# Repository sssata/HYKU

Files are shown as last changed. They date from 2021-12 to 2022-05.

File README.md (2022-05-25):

<p align="center">
  HYKU Logo
  <br>
  
</p>

[Store Link](https://www.tindie.com/products/kappachino/hyku-tablet/)

## First Time Setup Instructions, [Updated for HYKU Configurator v0.6](https://github.com/sssata/HYKU/releases/tag/v0.6.0)

1. Download HYKU_Configurator.exe from [here](https://github.com/sssata/HYKU/releases/tag/v0.6.0).
2. Plug in tablet with a USB-C cable. The LED should light up in a bright rainbow.
3. Deactivate tablet by holding down the keyswitchs for 1 second. The LED should turn blue.
4. Open the HYKU Configurator and open the Tools tab. Ensure tablet is recognized by the program with the "Connected" indicator at the bottom left.
5. Click Fetch Releases button, select latest version (v0.5 as of now), and press Update.
6. After Update completes, the tablet will need to be re-calibrated.
7. To Calibrate, position arm in a straight line as shown in image and press calibrate.
  
2. Reactivate tablet by holding down the keyswitchs for 1 second. The LED should turn bright rainbow.

## Configurator Usage Instructions
1. Configure tablet screen area and tablet area by entering values in the Area Settings tab.
2. Ensure Tablet is plugged in and recognized by the program with the "Connected" indicator at the bottom left.
3. Press the Upload button to apply settings and upload them to the tablet.

## Multi Monitor Instructions
abs mode pic

# What is it?

The HYKU Tablet is a novel drawing tablet-style input device designed from the ground up for osu!.

**Image Below Links to Video:**

IMAGE ALT TEXT HERE (https://www.youtube.com/watch?v=EKBiNb4UB-o)

## Why HYKU?

The goal of the HYKU is to create a pen tablet that is optimized for low latency. Most drawing tablets currently available offer polling rates below 200 Hz and have some level of hardware filtering that further decreases responsiveness, while the HYKU provides 600 Hz of raw sensor output.

<p align="center">
  HYKU Comparison Table
</p>

## Using the HYKU

**The HYKU tablet is plug and play and requires no drivers**. The screen and tablet area settings are written and saved on the tablet through the HYKU Configurator utility.

The configurator utility allows:
- Setting Screen area and Tablet area
- Setting cursor smoothing

<p align="center">
  HYKU Comparison Table
</p>

The tablet features a single button: 

### Download

The latest version of the configurator program can be found in [Releases](https://github.com/sssata/HYKU/releases).

## What's in the Box
- 1x HYKU Tablet, fully assembled
- 1x Tablet Pen, Removable 
- 1x 2m USB Type C to USB Type A Cable

## Tablet Specs

- **Polling Rate:** 600 Hz
- **Max Tablet Area:** Approx. 100mm x 80mm
- **Max Physical Resolution:** Approx. 0.091mm
- **Connector:** USB-C
- **Hot Swappable Switch**
- **OS Compatibility:** Windows 10 64-bit

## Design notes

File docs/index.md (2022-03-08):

<p align="center">
  HYKU Logo
  <br>
  
</p>

# Usage Guide

## First Time Setup Instructions

1. Plug in tablet with a USB-C cable (not included). The LED should light up in a bright rainbow.
2. Deactivate tablet by holding down the keyswitchs for 1 second. The LED should turn blue.
4. Open the HYKU Configurator and open the Tools tab. Ensure tablet is recognized by the program with the "Connected" indicator at the bottom left.
5. Click Fetch Releases button, select latest version, and press Update.
6. After Update completes, the tablet will need to be re-calibrated.
7. To Calibrate, position arm in a straight line as shown in image and press calibrate.
  
2. Reactivate tablet by holding down the keyswitchs for 1 second. The LED should turn bright rainbow.

## Configurator Usage Instructions
1. Configure tablet screen area and tablet area by entering values in the Area Settings tab.
2. Ensure Tablet is plugged in and recognized by the program with the "Connected" indicator at the bottom left.
3. Press the Upload button to apply settings and upload them to the tablet.

# What is it?

The HYKU Tablet is a novel drawing tablet-style input device designed from the ground up for osu!.

<p align="center">
<iframe width="800" height="500" src="https://www.youtube.com/embed/EKBiNb4UB-o" title="YouTube video player" frameborder="0" allow="accelerometer; autoplay; clipboard-write; encrypted-media; gyroscope; picture-in-picture" allowfullscreen></iframe>
</p>

## Why HYKU?

The goal of the HYKU is to create a pen tablet that is optimized for low latency. Most drawing tablets currently available offer polling rates below 200 Hz and have some level of hardware filtering that further decreases responsiveness, while the HYKU provides 600 Hz of raw sensor output.

<p align="center">
  HYKU Comparison Table
</p>

## Using the HYKU

**The HYKU tablet is plug and play and requires no drivers**. The screen and tablet area settings are written and saved on the tablet through the HYKU Configurator utility.

The configurator utility allows:
- Setting Screen area and Tablet area
- Setting cursor smoothing

<p align="center">
  HYKU Comparison Table
</p>

The tablet features a single button: 

### Download

The latest version of the configurator program can be found in [Releases](https://github.com/sssata/HYKU_CAD/releases/tag/v0.1).

## What's in the Box
- 1x HYKU Tablet, fully assembled
- 1x Tablet Pen, Removable 

## Tablet Specs

- **Polling Rate:** 600 Hz
- **Max Tablet Area:** Approx. 100mm x 80mm
- **Max Physical Resolution:** Approx. 0.091mm
- **Connector:** USB-C
- **Hot Swappable Switch**

## Tablet Usage Instructions

1. Plug in tablet with a USB-C cable (not included)
2. Press the key for right mouse button
3. Activate/deactivate tablet by holding down the key for 1 second
4. Configure tablet area and other options by using the HYKU Configurator.

## Configurator Usage Instructions
1. Configure tablet screen area and tablet area by entering values in the Area Settings tab.
2. Ensure Tablet is plugged in and reconized by the program with the "Connected" indicator at the bottom left.
3. Press the Upload button to apply settings and upload them to the tablet.

## Gallery

HYKU Tablett CAD







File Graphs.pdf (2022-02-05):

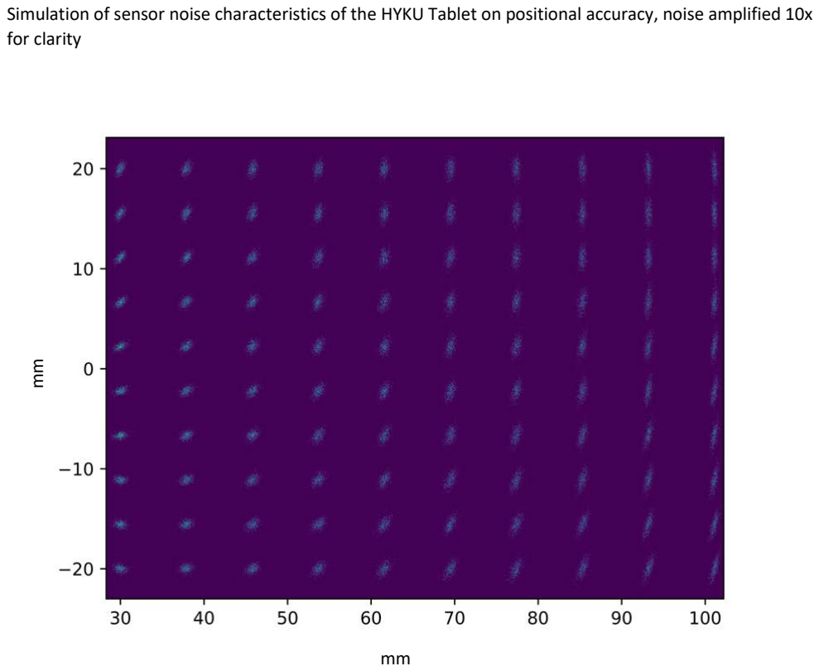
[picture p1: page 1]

Simulation of sensor noise characteristics of the HYKU Tablet on positional accuracy, noise amplified 10x for clarity

mm

mm

Effect of Polling Rate on Position Error during fast movements

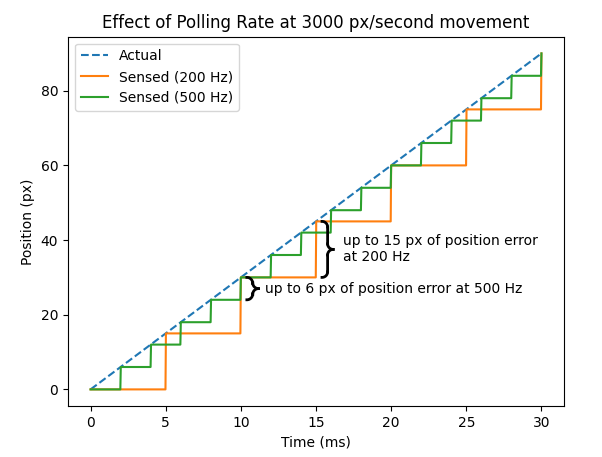
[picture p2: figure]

Note: 3000 px/sec simulates horizontal half cross screen jumps at 160 bpm, 1920x1080 resolution.

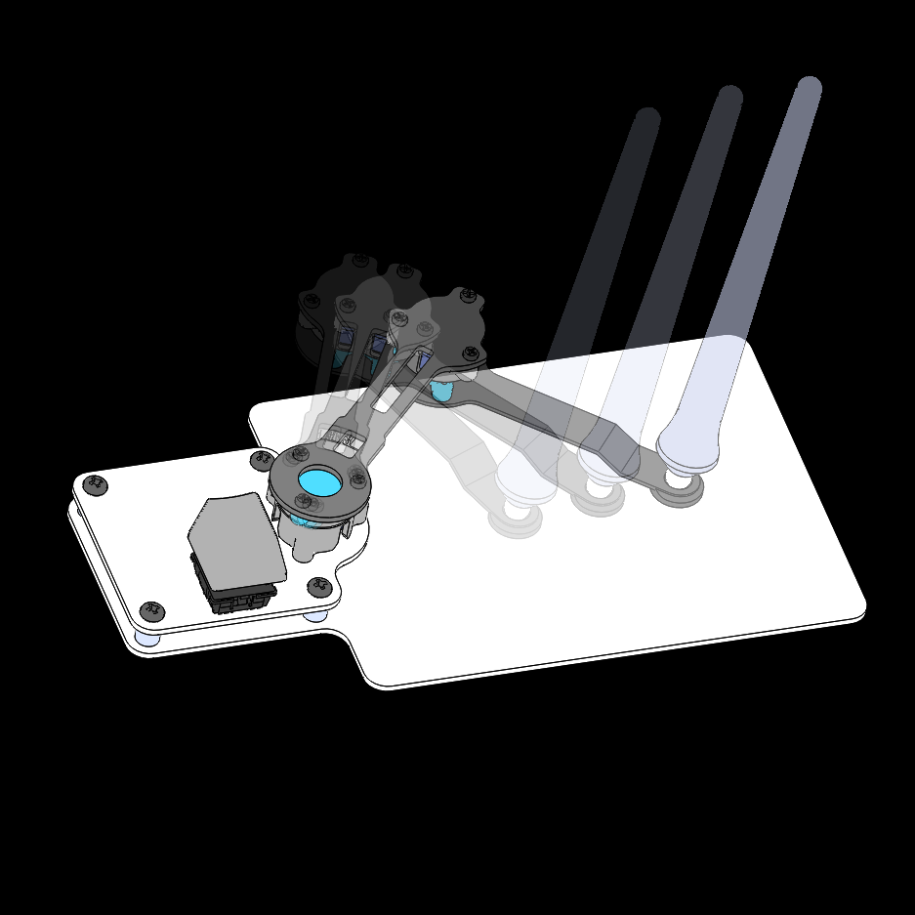
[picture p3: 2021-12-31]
pics/TBL2.png

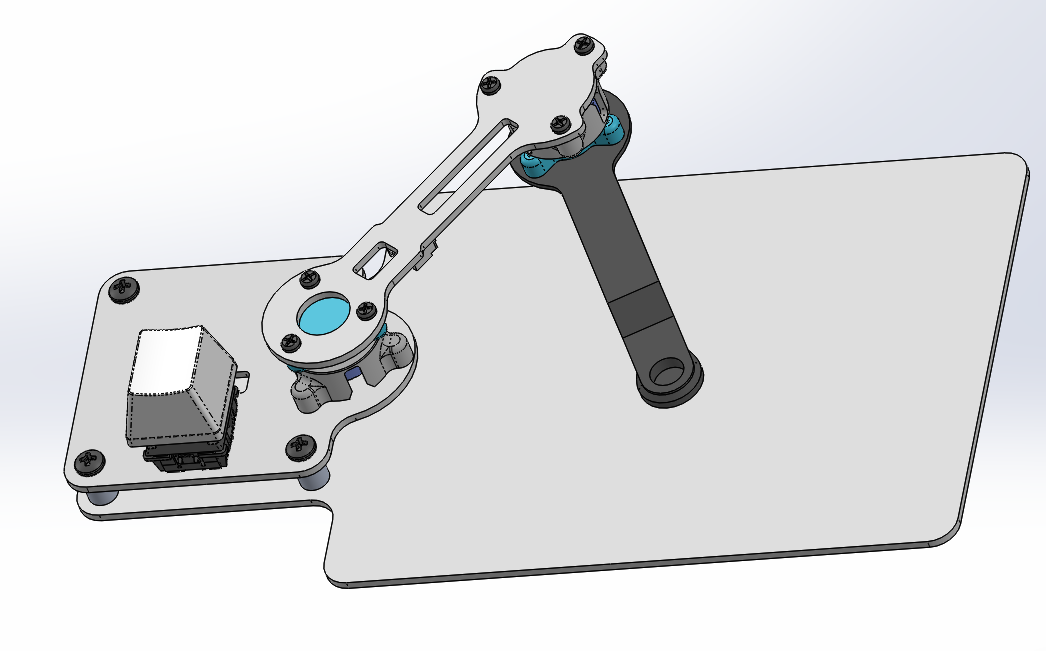
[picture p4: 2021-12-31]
CAD/cad exports/Screenshot 2021-12-27 175426.png

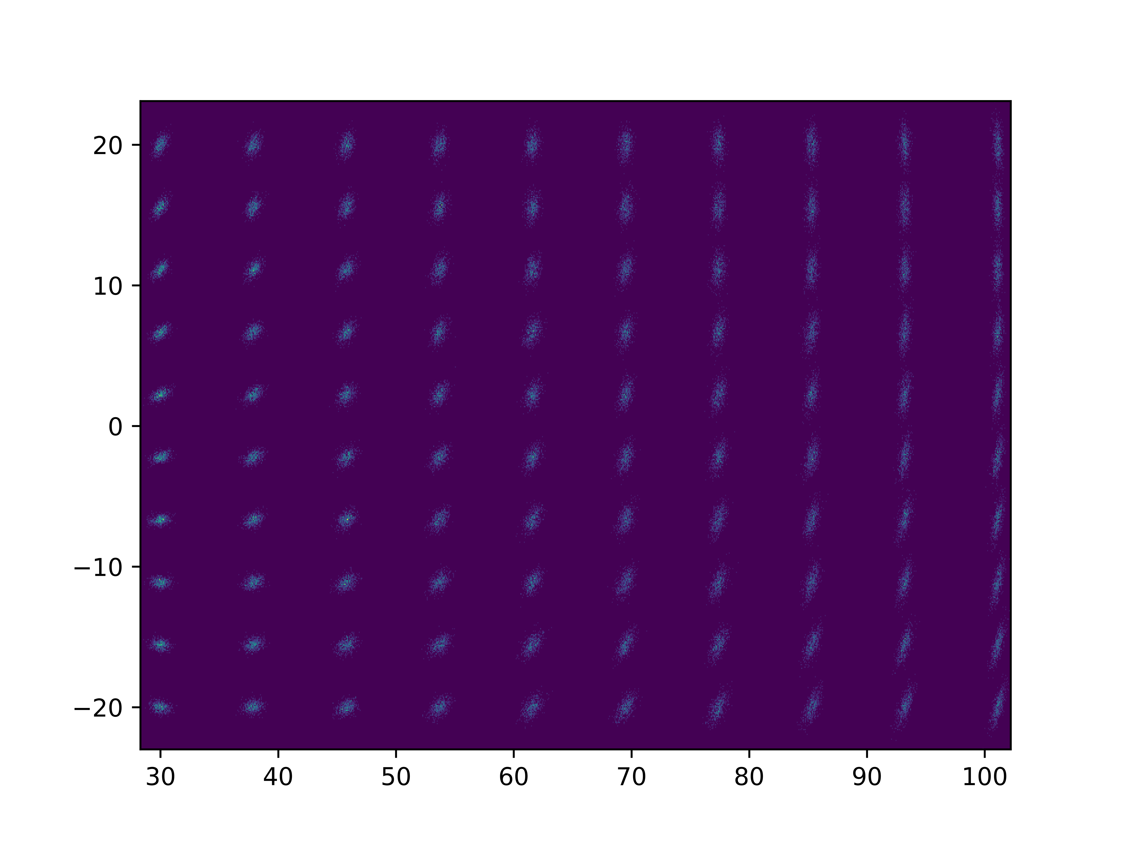
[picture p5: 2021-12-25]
python/output_2021-12-25.png

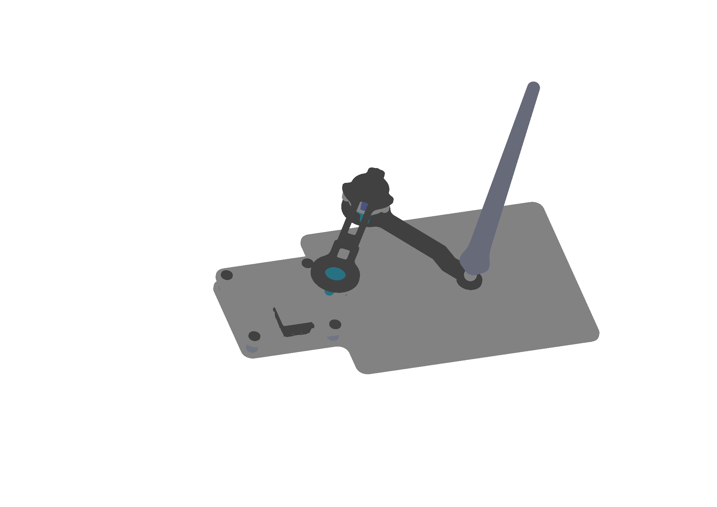
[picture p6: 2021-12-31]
CAD/cad exports/902 FINAL ASSY.JPG

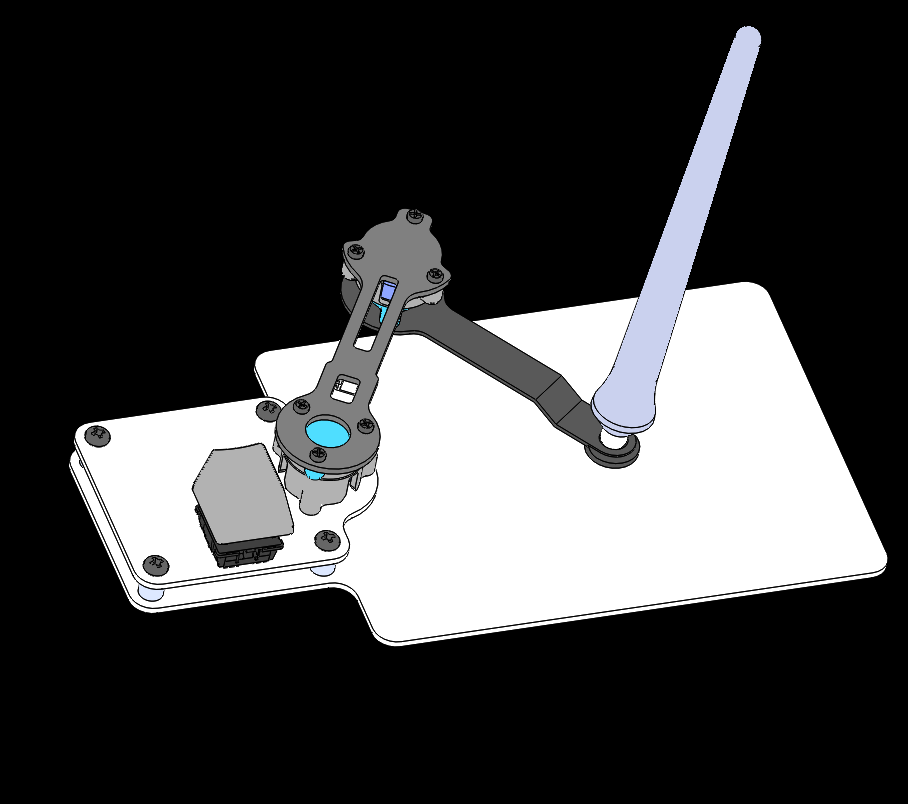
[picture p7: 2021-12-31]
CAD/cad exports/Screenshot 2021-12-27 183334.png

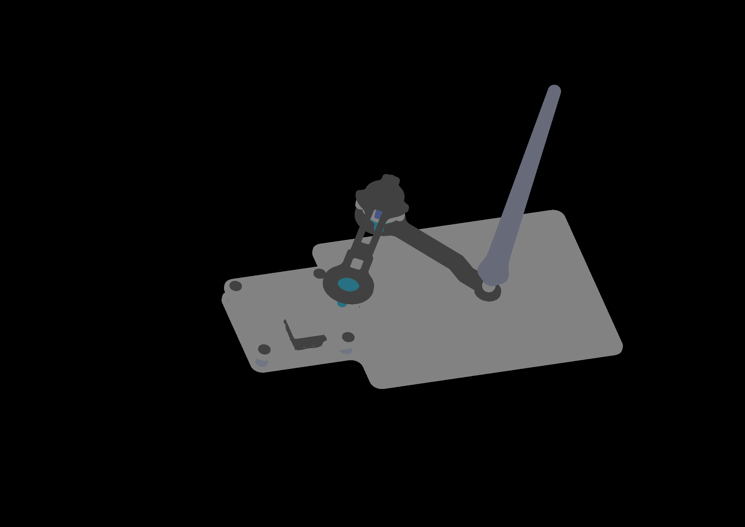
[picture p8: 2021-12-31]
CAD/cad exports/shot.PNG

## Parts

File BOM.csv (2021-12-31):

Source: | C:\Users\Tony\OneDrive - University of Waterloo (1)\TBL2\kicad\base\base.sch
Date: | 2021-12-25 16:54
Tool: | Eeschema (5.1.6)-1
Component Count: | 23
Ref | Value | Footprint | Datasheet | Manufacturer | Vendor
C1 | 100nF | Capacitor_SMD:C_0805_2012Metric | ~
H1 | MountingHole | MountingHole:MountingHole_3.2mm_M3_Pad_Via | ~
H2 | MountingHole | MountingHole:MountingHole_3.2mm_M3_Pad_Via | ~
H3 | MountingHole | MountingHole:MountingHole_3.2mm_M3_Pad_Via | ~
H4 | MountingHole | MountingHole:MountingHole_3.2mm_M3_Pad_Via | ~
J1 | Conn_01x05 | UltraLibrarian:SM05B-NSHSS-TBLFSN | ~
Q1 | MMBT3904 | Package_TO_SOT_SMD:SOT-23 | https://www.fairchildsemi.com/datasheets/2N/2N3904.pdf
Q2 | MMBT3904 | Package_TO_SOT_SMD:SOT-23 | https://www.fairchildsemi.com/datasheets/2N/2N3904.pdf
Q3 | MMBT3904 | Package_TO_SOT_SMD:SOT-23 | https://www.fairchildsemi.com/datasheets/2N/2N3904.pdf
R1 | 5.1k | Resistor_SMD:R_0805_2012Metric | ~
R2 | 10k | Resistor_SMD:R_0805_2012Metric | ~
R3 | 10k | Resistor_SMD:R_0805_2012Metric | ~
R4 | 10k | Resistor_SMD:R_0805_2012Metric | ~
R5 | 65R | Resistor_SMD:R_0805_2012Metric | ~
R6 | 10R | Resistor_SMD:R_0805_2012Metric | ~
R7 | 10R | Resistor_SMD:R_0805_2012Metric | ~
R8 | 5.1k | Resistor_SMD:R_0805_2012Metric | ~
R9 | 5.1k | Resistor_SMD:R_0805_2012Metric | ~
R10 | 5.1k | Resistor_SMD:R_0805_2012Metric | ~
SW2 | SW_SPST_LED_RGB | keyswitches:Kailh_socket_MX_SMD_RGB
U1 | Seeeduiono_Xiao | KeypadLib:Seeeduino_Xiao
U2 | NC7SB3257P6X | Package_TO_SOT_SMD:SOT-363_SC-70-6
U3 | AS5600 | Package_SO:SOIC-8_3.9x4.9mm_P1.27mm

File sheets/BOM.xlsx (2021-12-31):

Unit: One Sellable product
Piece: Non-sellable Individual part
Cost: Amount Paid For parts/shipping
 |  |  |  |  |  | Prod Run A |  |  |  | 48.456 | Prod Run B |  |  |  | 37.0345 | Prod Run C |  |  |  | 32.6252
Subsystem | Name | Description | REF Number (s) | CAD Part Number | MFG Part Number | Qty of Units | Pieces/Unit | Total Pieces | Total Cost | Cost/Unit | Qty of Units | Pieces/Unit | Total Pieces | Total Cost | Cost/Unit | Qty of Units | Pieces/Unit | Total Pieces | Total Cost | Cost/Unit
Base | Base PCB | Base PCB | - | 011 | - | 5 | 1 | 5 | 21 | 4.2 | 20 | 1 | 20 | 22.98 | 1.149 | 50 | 1 | 50 | 44.73 | 0.8946
Base | Capacitor | 0805 100nF | C1, C1 | - | 08055C104KAT2A | 5 | 2 | 10 | 1.01 | 0.202 | 20 | 2 | 40 | 4.04 | 0.202 | 50 | 2 | 100 | 4.46 | 0.0892
Mixed | Connector | JST NSH 5 Pin | J1, J1 | - | SM05B-NSHSS-TBLFSN | 5 | 2 | 10 | 9.11 | 1.822 | 20 | 2 | 40 | 36.44 | 1.822 | 50 | 2 | 100 | 81.8 | 1.636
Base | BJT | LED Switch BJT | Q1, Q2, Q3 | - | BC847BW-7-F | 5 | 3 | 15 | 4.21 | 0.842 | 20 | 3 | 60 | 16.86 | 0.843 | 50 | 3 | 150 | 22.88 | 0.4576
Base | Resistor | 0805 5.1k | R1, R8, R9, R10 | - | RC0805FR-075K1L | 5 | 4 | 20 | 1.24 | 0.248 | 20 | 4 | 80 | 2.48 | 0.124 | 50 | 4 | 200 | 4.96 | 0.0992
Base | Resistor | 0805 10k | R2, R3, R4 | - | RMCF0805FT10K0 | 5 | 3 | 15 | 0.6 | 0.12 | 20 | 3 | 60 | 1.6 | 0.08 | 50 | 3 | 150 | 2.4 | 0.048
Base | Resistor | 0805 68R | R5 | - | RC0805JR-0768RL | 5 | 1 | 5 | 0.75 | 0.15 | 20 | 1 | 20 | 1.06 | 0.053 | 50 | 1 | 50 | 2.13 | 0.0426
Base | Resistor | 0805 10R | R6, R7 | - | RC0805FR-0710RL | 5 | 2 | 10 | 1.22 | 0.244 | 20 | 2 | 40 | 4.88 | 0.244 | 50 | 2 | 100 | 4.98 | 0.0996
Base | Keyswitch | MX Switch | SW2 | - | - | 5 | 1 | 5 | 1.25 | 0.25 | 20 | 1 | 20 | 5 | 0.25 | 50 | 1 | 50 | 12.5 | 0.25
Base | Keycap | Keycap | - | - | - | 5 | 1 | 5 | 1.5 | 0.3 | 20 | 1 | 20 | 6 | 0.3 | 50 | 1 | 50 | 15 | 0.3
Base | Seeeduino Xiao | MCU | U1 | - | 102010328 | 5 | 1 | 5 | 37.25 | 7.45 | 20 | 1 | 20 | 149 | 7.45 | 50 | 1 | 50 | 372.5 | 7.45
Base | I2C Switch | I2C Switch | U2 | - | NC7SB3257P6X | 5 | 1 | 5 | 4.1 | 0.82 | 20 | 1 | 20 | 14.14 | 0.707 | 50 | 1 | 50 | 32.94 | 0.6588
Mixed | Encoder | Rot Hall Encoder 12-Bit | U3, U1 | - | AS5600 | 5 | 2 | 10 | 40.44 | 8.088 | 20 | 2 | 40 | 152.98 | 7.649 | 50 | 2 | 100 | 331.42 | 6.6284
Base | RGB LED | RGB Switch LED | - | - | QBLP677R-RGB | 5 | 1 | 5 | 7.25 | 1.45 | 20 | 1 | 20 | 18.26 | 0.913 | 50 | 1 | 50 | 45.65 | 0.913
Mixed | Wire Assy | 10CM JST NSH 5-Pin Wire | - | - | - | 5 | 1 | 5 | 10 | 2 | 20 | 1 | 20 | 40 | 2 | 50 | 1 | 50 | 100 | 2
Area | Standoff | 4-40 1/4 inch standoff | - | 020 | 4883 | 5 | 4 | 20 | 17 | 3.4 | 20 | 4 | 80 | 61.63 | 3.0815 | 50 | 4 | 200 | 116.32 | 2.3264
Area | Area PCB | Area PCB | - | - | - | 5 | 1 | 5 | 26.95 | 5.39 | 20 | 1 | 20 | 74.62 | 3.731 | 50 | 1 | 50 | 142.8 | 2.856
Mixed | #4-40 Screw | #4-40 1/4 Screw | - | - | - | 5 | 4 | 20 | 3.02 | 0.604 | 20 | 4 | 80 | 3.02 | 0.151 | 50 | 4 | 200 | 6.04 | 0.1208
Upper Arm | Upper Arm PCB | Upper Arm PCB | - | 008 | - | 5 | 1 | 5 | 21 | 4.2 | 20 | 1 | 20 | 22.98 | 1.149 | 50 | 1 | 50 | 44.73 | 0.8946
Mixed | Magnet | 6x2.5mm N35 Radial | - | 009 | 8995 | 5 | 2 | 10 | 4 | 0.8 | 20 | 2 | 40 | 14.27 | 0.7135 | 50 | 2 | 100 | 26.74 | 0.5348
Mixed | M2x5 ST Screw | M2x5 ST Screw | - | - | - | 5 | 12 | 60 | 19.38 | 3.876 | 20 | 12 | 240 | 48.45 | 2.4225 | 50 | 12 | 600 | 116.28 | 2.3256
Mixed | Bearing Mount Male | Bearing Mount Male | - | - | - | 5 | 2 | 10 | 5 | 1 | 20 | 2 | 40 | 20 | 1 | 50 | 2 | 100 | 50 | 1
Mixed | Bearing Mount Female | Bearing Mount Female | - | - | - | 5 | 2 | 10 | 5 | 1 | 20 | 2 | 40 | 20 | 1 | 50 | 2 | 100 | 50 | 1
 |  |  |  |  |  | 5 |  |  |  | 0 | 20 | 0 | 0 |  | 0 | 50 | 0 | 0 |  | 0
 |  |  |  |  |  | 5 |  |  |  | 0 | 20 | 0 | 0 |  | 0 | 50 | 0 | 0 |  | 0
 |  |  |  |  |  | 5 |  |  |  | 0 | 20 | 0 | 0 |  | 0 | 50 | 0 | 0 |  | 0
 |  |  |  |  |  | 5 |  |  |  | 0 | 20 | 0 | 0 |  | 0 | 50 | 0 | 0 |  | 0
 |  |  |  |  |  | 5 |  |  |  | 0 | 20 | 0 | 0 |  | 0 | 50 | 0 | 0 |  | 0
 |  |  |  |  |  | 5 |  |  |  | 0 | 20 | 0 | 0 |  | 0 | 50 | 0 | 0 |  | 0
 |  |  |  |  |  | 5 |  |  |  | 0 | 20 | 0 | 0 |  | 0 | 50 | 0 | 0 |  | 0
 |  |  |  |  |  | 5 |  |  |  | 0 | 20 | 0 | 0 |  | 0 | 50 | 0 | 0 |  | 0
 |  |  |  |  |  |  |  |  |  |  |  | 0 |  |  |  | 50 | 0 | 0 |  | 0
 |  |  |  |  |  |  |  |  |  |  |  | 0 |  |  |  |  | 0
 |  |  |  |  |  |  |  |  |  |  |  | 0 |  |  |  |  | 0
 |  |  |  |  |  |  |  |  |  |  |  | 0 |  |  |  |  | 0
 |  |  |  |  |  |  |  |  |  |  |  | 0 |  |  |  |  | 0
 |  |  |  |  |  |  |  |  |  |  |  | 0 |  |  |  |  | 0
 |  |  |  |  |  |  |  |  |  |  |  | 0 |  |  |  |  | 0
 |  |  |  |  |  |  |  |  |  |  |  | 0 |  |  |  |  | 0
 |  |  |  |  |  |  |  |  |  |  |  | 0 |  |  |  |  | 0
 |  |  |  |  |  |  |  |  |  |  |  | 0 |  |  |  |  | 0
 |  |  |  |  |  |  |  |  |  |  |  | 0 |  |  |  |  | 0
 |  |  |  |  |  |  |  |  |  |  |  | 0 |  |  |  |  | 0
 |  |  |  |  |  |  |  |  |  |  |  | 0 |  |  |  |  | 0
 |  |  |  |  |  |  |  |  |  |  |  | 0 |  |  |  |  | 0
 |  |  |  |  |  |  |  |  |  |  |  | 0 |  |  |  |  | 0
 |  |  |  |  |  |  |  |  |  |  |  | 0 |  |  |  |  | 0
 |  |  |  |  |  |  |  |  |  |  |  | 0 |  |  |  |  | 0
 |  |  |  |  |  |  |  |  |  |  |  | 0 |  |  |  |  | 0
 |  |  |  |  |  |  |  |  |  |  |  | 0 |  |  |  |  | 0
 |  |  |  |  |  |  |  |  |  |  |  | 0 |  |  |  |  | 0
 |  |  |  |  |  |  |  |  |  |  |  | 0 |  |  |  |  | 0
 |  |  |  |  |  |  |  |  |  |  |  | 0 |  |  |  |  | 0
 |  |  |  |  |  |  |  |  |  |  |  | 0 |  |  |  |  | 0
 |  |  |  |  |  |  |  |  |  |  |  | 0 |  |  |  |  | 0
 |  |  |  |  |  |  |  |  |  |  |  | 0 |  |  |  |  | 0
 |  |  |  |  |  |  |  |  |  |  |  | 0 |  |  |  |  | 0
 |  |  |  |  |  |  |  |  |  |  |  | 0 |  |  |  |  | 0
 |  |  |  |  |  |  |  |  |  |  |  | 0 |  |  |  |  | 0
 |  |  |  |  |  |  |  |  |  |  |  | 0 |  |  |  |  | 0
 |  |  |  |  |  |  |  |  |  |  |  | 0 |  |  |  |  | 0
 |  |  |  |  |  |  |  |  |  |  |  | 0 |  |  |  |  | 0
 |  |  |  |  |  |  |  |  |  |  |  | 0 |  |  |  |  | 0
 |  |  |  |  |  |  |  |  |  |  |  | 0 |  |  |  |  | 0
 |  |  |  |  |  |  |  |  |  |  |  | 0 |  |  |  |  | 0
 |  |  |  |  |  |  |  |  |  |  |  | 0 |  |  |  |  | 0
 |  |  |  |  |  |  |  |  |  |  |  | 0 |  |  |  |  | 0
 |  |  |  |  |  |  |  |  |  |  |  | 0 |  |  |  |  | 0
 |  |  |  |  |  |  |  |  |  |  |  | 0 |  |  |  |  | 0
 |  |  |  |  |  |  |  |  |  |  |  | 0 |  |  |  |  | 0
 |  |  |  |  |  |  |  |  |  |  |  | 0 |  |  |  |  | 0
 |  |  |  |  |  |  |  |  |  |  |  | 0 |  |  |  |  | 0
 |  |  |  |  |  |  |  |  |  |  |  | 0 |  |  |  |  | 0
 |  |  |  |  |  |  |  |  |  |  |  | 0 |  |  |  |  | 0
 |  |  |  |  |  |  |  |  |  |  |  | 0 |  |  |  |  | 0
 |  |  |  |  |  |  |  |  |  |  |  | 0 |  |  |  |  | 0
 |  |  |  |  |  |  |  |  |  |  |  | 0 |  |  |  |  | 0
 |  |  |  |  |  |  |  |  |  |  |  | 0 |  |  |  |  | 0
 |  |  |  |  |  |  |  |  |  |  |  | 0 |  |  |  |  | 0
 |  |  |  |  |  |  |  |  |  |  |  | 0 |  |  |  |  | 0
 |  |  |  |  |  |  |  |  |  |  |  | 0 |  |  |  |  | 0
 |  |  |  |  |  |  |  |  |  |  |  | 0 |  |  |  |  | 0
 |  |  |  |  |  |  |  |  |  |  |  | 0 |  |  |  |  | 0
 |  |  |  |  |  |  |  |  |  |  |  | 0 |  |  |  |  | 0
 |  |  |  |  |  |  |  |  |  |  |  | 0 |  |  |  |  | 0

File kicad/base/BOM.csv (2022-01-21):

Comment | Designator | Footprint | LCSC
100nF | C1 | Capacitor_SMD:C_0805_2012Metric | C49678
MMBT3904 | Q1,Q2,Q3 | Package_TO_SOT_SMD:SOT-23 | C20526
5.1k | R1,R8,R9,R10 | Resistor_SMD:R_0805_2012Metric | C27834
10k | R2,R3,R4 | Resistor_SMD:R_0805_2012Metric | C17414
68R | R5 | Resistor_SMD:R_0805_2012Metric | C17802
10R | R6,R7 | Resistor_SMD:R_0805_2012Metric | C17415

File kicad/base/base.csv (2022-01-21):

Id | Designator | Package | Quantity | Designation | Supplier and ref
1 | REF**,REF**,REF** | JLCPCB Tooling Hole | 3 | JLCPCB Tooling Hole
2 | U3 | SOIC-8_3.9x4.9mm_P1.27mm | 1 | AS5600
3 | U1 | Seeeduino_Xiao | 1 | Seeeduiono_Xiao
4 | SW2 | Kailh_socket_MX_SMD_RGB | 1 | SW_SPST_LED_RGB
5 | R10,R9,R8,R1 | R_0805_2012Metric | 4 | 5.1k
6 | Q3,Q2,Q1 | SOT-23 | 3 | MMBT3904
7 | R7,R6 | R_0805_2012Metric | 2 | 10R
8 | R5 | R_0805_2012Metric | 1 | 68R
9 | J1 | SM05B-NSHSS-TBLFSN | 1 | TO ARM
10 | H4,H3,H2,H1 | MountingHole_3.2mm_M3_Pad_Via | 4 | MountingHole
11 | C1 | C_0805_2012Metric | 1 | 100nF
12 | R2,R3,R4 | R_0805_2012Metric | 3 | 10k
13 | U2 | SOT-363_SC-70-6 | 1 | NC7SB3257P6X

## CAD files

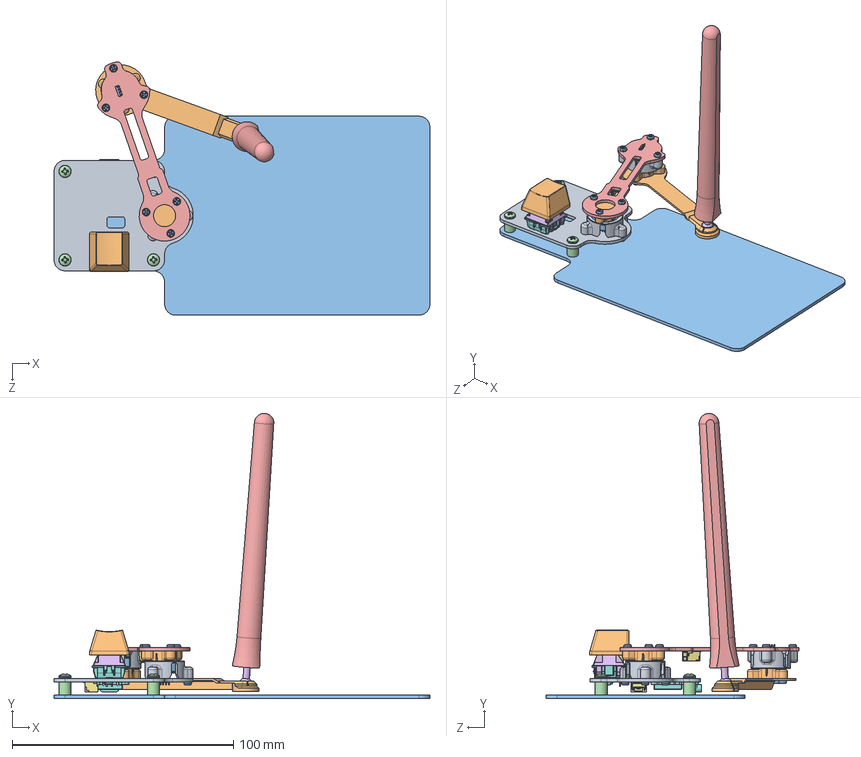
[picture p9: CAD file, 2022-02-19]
CAD/902 FINAL ASSY.SLDASM
170.0 x 129.0 x 114.6 mm
005 BEARING FEMALE PLATE x 2
006 BEARING MALE PLATE x 2
007 6700ZZ bearing x 2
009 6x2mm MAGNET x 2
008 UPPER ARM PCB
013 AS5600 SOIC-8 x 2
014 JST NSH 5 PIN BOARD SIDE x 2
012 SeeeduinoXiao3D
011 BASE PCB
016 LOWER ARM PCB
017 AREA PCB
020 STANDOFF 3x6 x 4
Cherry MX Stem
Cherry MX Top Housing
Cherry MX Bottom Housing
Cherry MX Pins
Cherry MX OEM R4 Keycap
99461A914_Phillips Rounded Head Thread-Forming Screws x 12
91772A106_Passivated 18-8 Stainless Steel Pan Head Phillips Screw x 4
021 PEN
022 PEN NIB

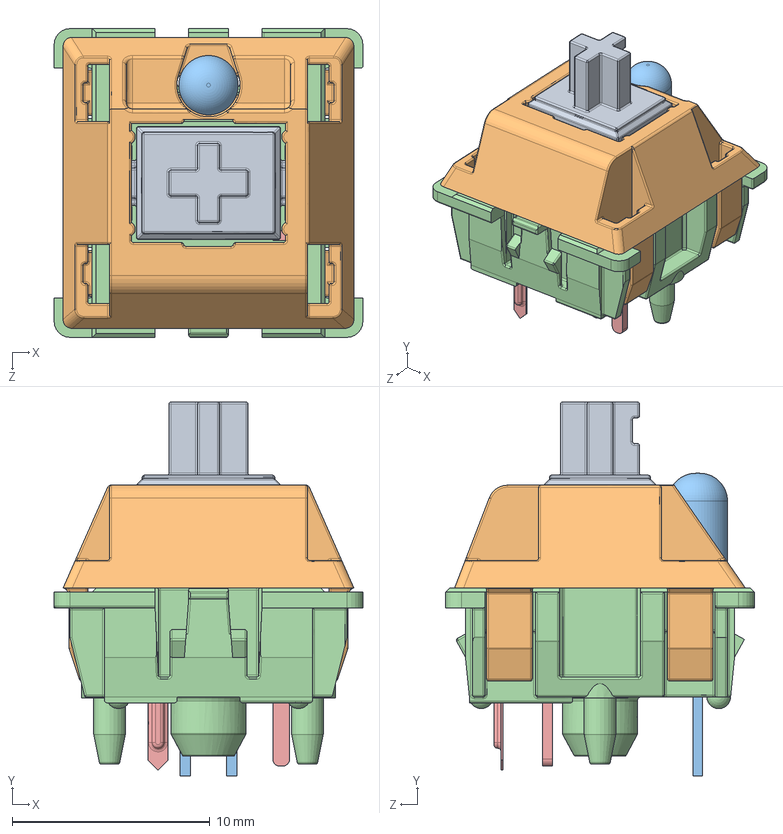
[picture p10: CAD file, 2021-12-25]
CAD/imported/CHERRY MX Switch.SLDASM
15.6 x 18.9 x 15.6 mm
Cherry MX Stem
Cherry MX Top Housing
Cherry MX Bottom Housing
Cherry MX Pins

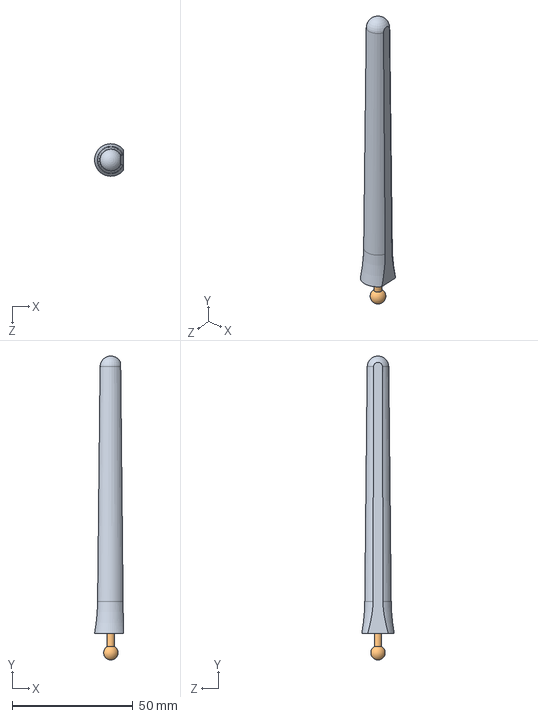
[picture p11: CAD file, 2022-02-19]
CAD/906 PEN ASSY.SLDASM
12.0 x 126.0 x 13.5 mm
021 PEN
022 PEN NIB

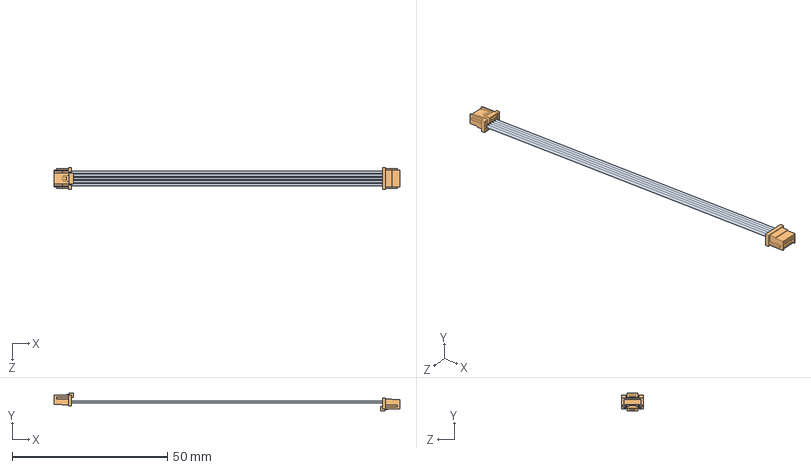
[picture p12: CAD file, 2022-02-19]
CAD/905 WIRE ASSY.SLDASM
111.4 x 5.75 x 7.00 mm
018 UPPER WIRE
015 JST NSH 5 PIN WIRE SIDE x 2
020 JST NSH CRIMP x 10

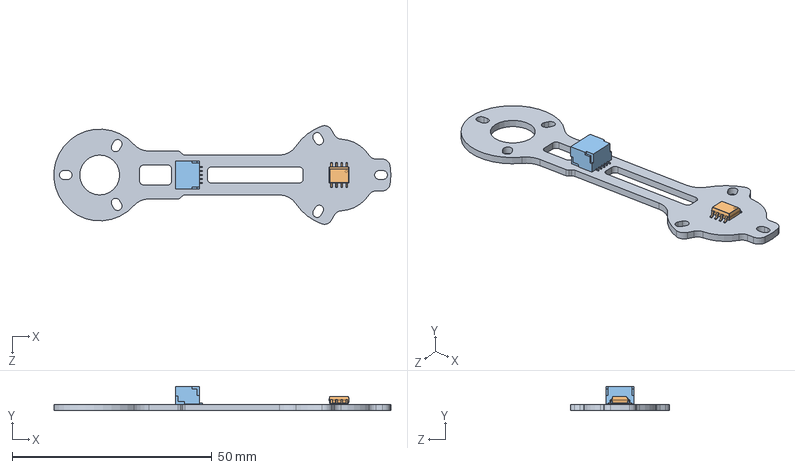
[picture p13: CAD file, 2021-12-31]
CAD/904 UPPER ARM PCB ASSY.SLDASM
84.4 x 6.10 x 24.7 mm
008 UPPER ARM PCB
013 AS5600 SOIC-8
014 JST NSH 5 PIN BOARD SIDE

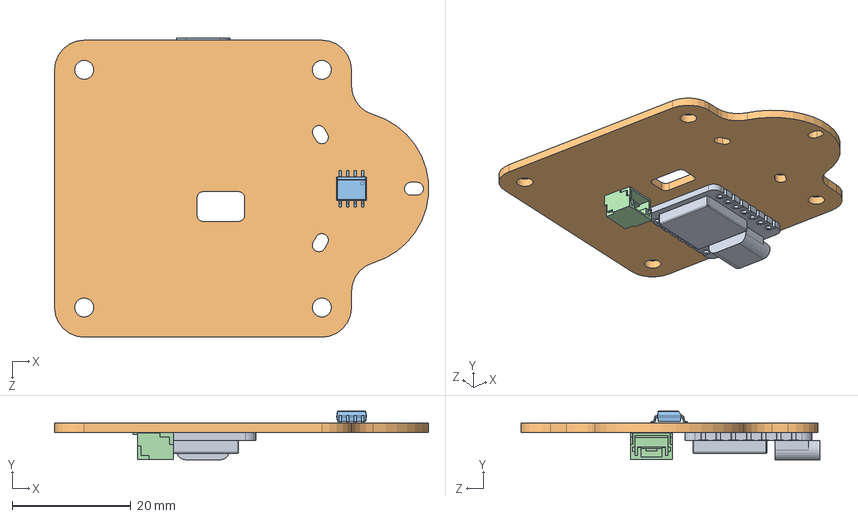
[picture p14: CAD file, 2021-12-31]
CAD/903 BASE PCB ASSY.SLDASM
63.0 x 8.20 x 50.4 mm
012 SeeeduinoXiao3D
011 BASE PCB
013 AS5600 SOIC-8
014 JST NSH 5 PIN BOARD SIDE

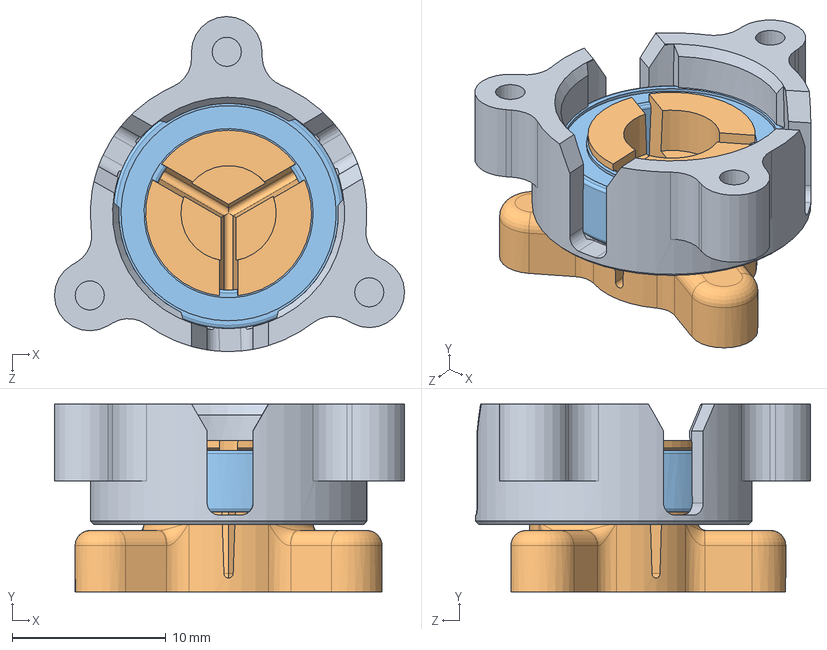
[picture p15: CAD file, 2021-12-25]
CAD/901 BEARING ASSY.SLDASM
22.8 x 12.2 x 21.8 mm
005 BEARING FEMALE PLATE
006 BEARING MALE PLATE
007 6700ZZ bearing

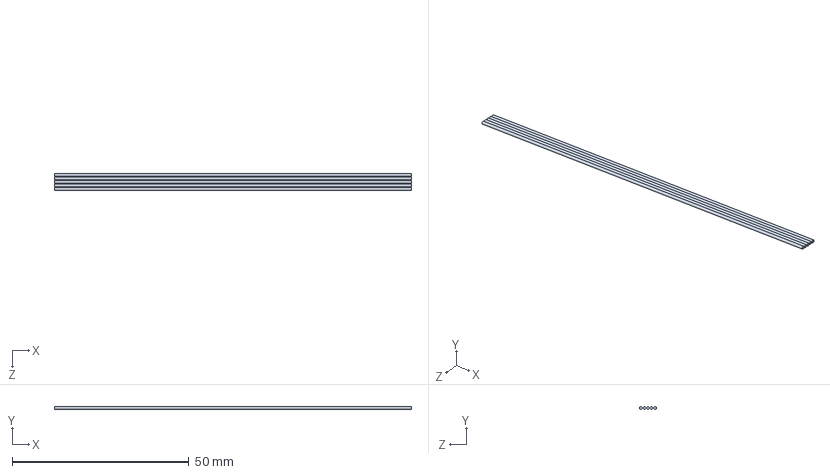
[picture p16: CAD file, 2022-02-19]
CAD/018 UPPER WIRE.SLDPRT
101.0 x 0.8 x 4.80 mm

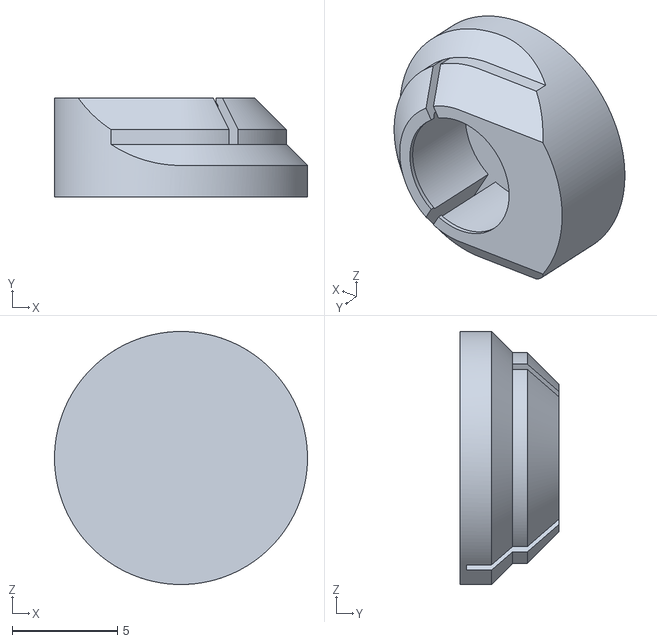
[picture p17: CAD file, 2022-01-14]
CAD/cad exports/016 LOWER ARM TEST1.STL
12.0 x 4.70 x 12.0

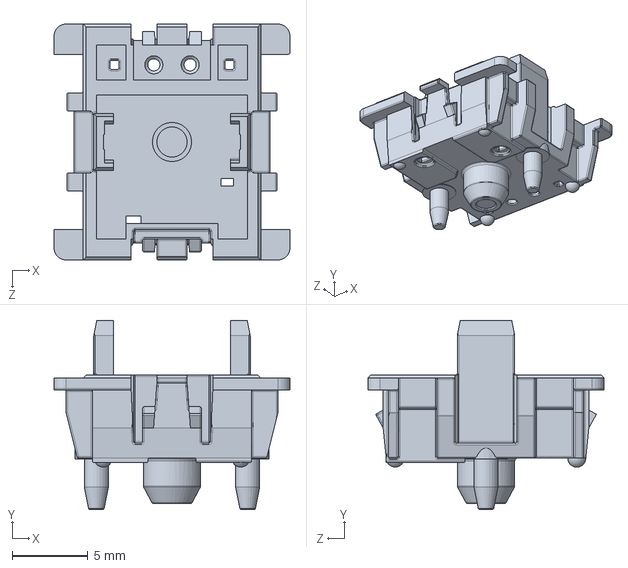
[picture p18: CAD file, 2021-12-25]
CAD/imported/Cherry MX Bottom Housing.SLDPRT
15.6 x 12.5 x 15.6 mm

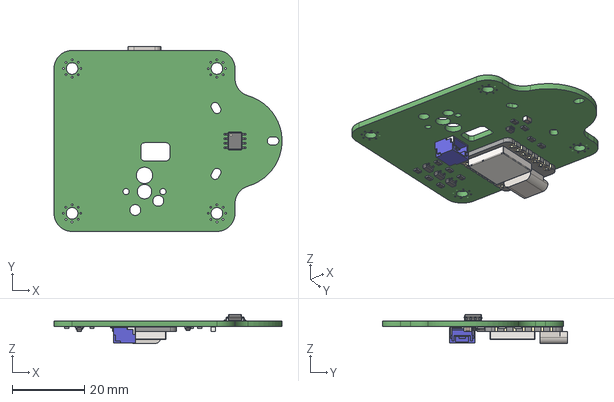
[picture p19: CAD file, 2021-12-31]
kicad/base/kicad export/base.step
63.0 x 51.1 x 8.05 mm

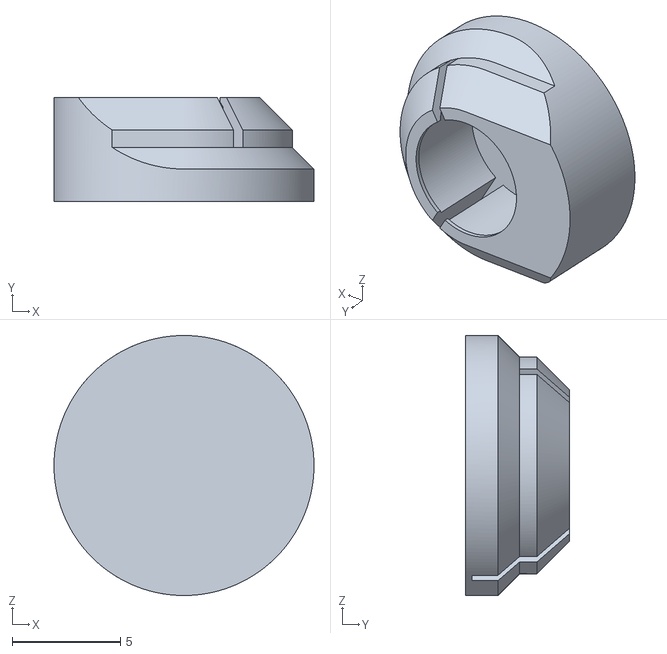
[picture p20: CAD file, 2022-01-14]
CAD/cad exports/016 LOWER ARM TEST3.STL
12.0 x 4.80 x 12.0

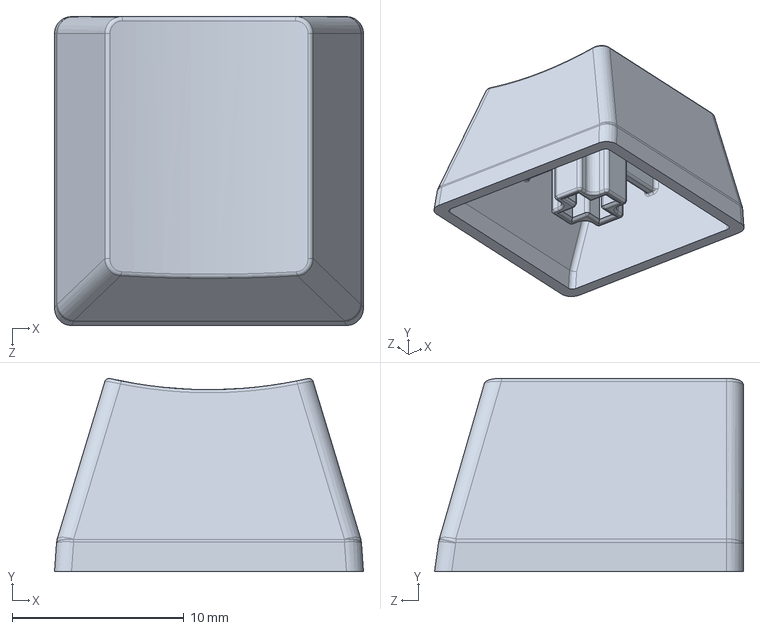
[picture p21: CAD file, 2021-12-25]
CAD/imported/Cherry MX OEM R4 Keycap.SLDPRT
18.0 x 11.3 x 18.0 mm

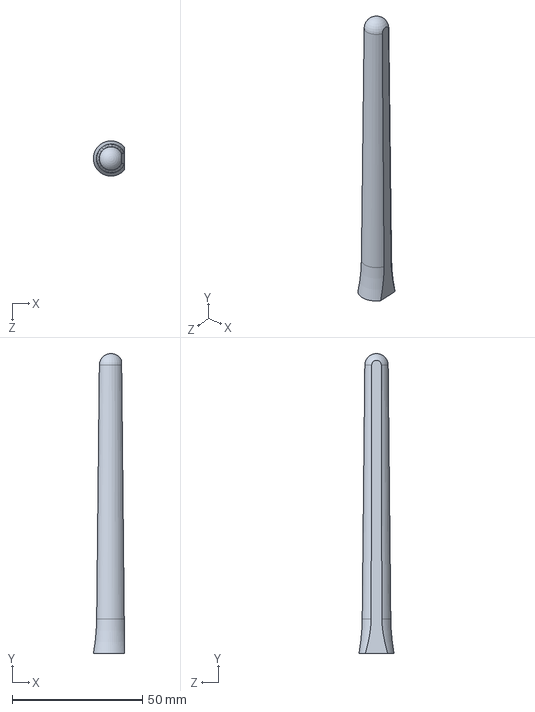
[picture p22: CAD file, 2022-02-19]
CAD/021 PEN.SLDPRT
12.0 x 115.0 x 13.5 mm

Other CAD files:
CAD/cad exports/016 LOWER ARM TEST2.STL
CAD/cad exports/008 UPPER ARM PCB2.DXF
CAD/imported/Cherry MX Pins.SLDPRT
CAD/006 BEARING MALE PLATE.SLDPRT
CAD/001 BASE REV2.SLDPRT
CAD/002 UPPER ARM REV2.SLDPRT
CAD/003 LOWER ARM REV2.SLDPRT
CAD/004 MR85ZZ bearing.SLDPRT
CAD/005 BEARING FEMALE PLATE.SLDPRT
CAD/007 6700ZZ bearing.SLDPRT
CAD/008 UPPER ARM PCB.SLDPRT
CAD/009 6x2mm MAGNET.SLDPRT
CAD/010 BASE KICAD EXP.SLDPRT
CAD/010 BASE.SLDPRT
CAD/011 BASE PCB.SLDPRT
CAD/012 SeeeduinoXiao3D.SLDPRT
CAD/013 AS5600 SOIC-8.SLDPRT
CAD/014 JST NSH 5 PIN BOARD SIDE.SLDPRT
CAD/014.SLDDRW
CAD/015 JST NSH 5 PIN WIRE SIDE.SLDPRT
CAD/016 LOWER ARM PCB.SLDPRT
CAD/017 AREA PCB.SLDPRT
CAD/019.SLDPRT
CAD/020 JST NSH CRIMP.SLDPRT
CAD/020 STANDOFF 3x6.SLDPRT
CAD/022 PEN NIB.SLDPRT
CAD/905 WIRE ASSY.SLDDRW
CAD/905.SLDDRW
CAD/cad exports/004 MR85ZZ bearing.STL
CAD/cad exports/005 BEARING FEMALE PLATE.STL
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

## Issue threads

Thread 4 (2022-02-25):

Multi monitor support

jasonhahm, 2022-02-25:
It doesn't seem like it's working with multi monitor environment.
I currently have three monitors, and the configurator still shows 1920*1080, and the screen area is basically stretched on the tablet.
Can we have an option to choose one of the active monitors?

sssata, 2022-02-25:
Hi thanks for bringing this up, multi-monitor support is currently a work in progress.

sssata, 2022-03-06:
Update: still on it, for now try activating the "Map absolute raw input to the osu! window" setting in osu.
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

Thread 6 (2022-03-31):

config.exe unable to detect device

Jaymusta, 2022-03-31:
Hi there,

I've recently attempted to update the firmware for my tablet to v0.5, but it would seem that HYKU_Configurator.exe stopped responding shortly after the CMD window popped up.

I went ahead and restarted the executable, but it would seem that the program isn't able to detect the tablet anymore.

I suspect that the tablet may be stuck in a certain mode given that its LED is fading between green and yellow/orange as it may have been waiting for the executable to flash the firmware to the device around when it stopped responding.

### Some details that may have contributed to this happening include:

- I replaced the version of the executable to the latest build (v0.5) from a previous version that didn't have a third tab dedicated to calibrating and flashing new firmware to the device before doing any of this
- Upon seeing how that new executable required me to update the firmware on the device to v0.5 in order to upload any settings, I went ahead and fetched the firmware in that 3rd tab and attempted to start that process with v0.5 of the .exe instead of v0.4 of the .exe

### What I have tried to remedy this issue so far:

- reconnecting the tablet with the executable open/running
- reconnecting the tablet and holding down the gateron switch while plugging the cable back into it with the executable open/running
- ^doing both of those things with the executable closed, and then opening/running the executable
- ^doing all of the above with the previous version of the executable that I was using prior to this

### Here are the error prompts I currently get when trying to upload any settings or flash any firmware to the device:
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

An additional detail I just now found is that Device Manager does seem to respond to me disconnecting/reconnecting the device to the computer along with the usb device connection sounds playing.

If my tablet is indeed stuck in a certain mode waiting for the .exe to flash firmware to it, is there a way to reset the device? (so that it would able to reconnect to my pc in its "factory" default mode which would be detectable to the .exe)

sssata, 2022-03-31:
Hi Jaymusta, sorry you're having trouble and really appreciate the detailed issue report.

Can you try entering bootloader mode as described [here](https://wiki.seeedstudio.com/Seeeduino-XIAO/#enter-bootloader-mode)? You may need to unscrew the main board from the base to access the pads, and you may want to use tape to cover the USB-C connector and any surrounding pads so you don't accidentally short them.

The pads to short should be somewhere around here:
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

After entering the bootloader mode, both the green and yellow LEDs beside the USB connector should be lit and the device should be recognized by Windows as a USB Serial Device. At this point, you can try re-uploading the v0.5 firmware through the configurator program.

Jaymusta, 2022-04-01:
Hey thanks for replying,

Upon taking a better look at those LEDs, it seems that the green LED was actually staying on with the yellow LED slowly fading on and off.

I went ahead and followed those instructions after finding those 2 contact pads next to the USB-C port as you specified, and the yellow LED did respond to me shorting those 2 contact pads with tweezers in that it stayed off while the tweezers were maintaining contact with the pads.

Unfortunately, it seems that the yellow LED just went back to its previous behavior of slowly fading on and off after flickering once right after shorting those pads twice as instructed via that link you provided.

It also seems that the way my PC is reading the device hasn't changed either since HYKU_Configurator.exe didn't recognize the device after shorting those pads.

I did find the device within Device Manager:
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

Along with the last event my pc logged with the device in Event Viewer from about 2 hours ago:

> Source: UserPnp
> Event ID: 20001
> Task Category: (7005)

> Driver Management concluded the process to install driver wpdfs.inf_amd64_aade15d7efbed3c9 for Device Instance ID SWD\WPDBUSENUM\_??_USBSTOR#DISK&VEN_SEEEDUIN&PROD_O_XIAO&REV_1.00#8&1241C78E&0&B8335C6650555233362E3120FF081738&0#{53F56307-B6BF-11D0-94F2-00A0C91EFB8B} with the following status: 0x0.

^All that information might be doing is just confirming that my PC is still not recognizing the device properly, but I went ahead and included it anyways just in case.

Jaymusta, 2022-04-02:
I ended up going further down the rabbit hole regarding what came up in the google search results when searching for similar experiences with the Seeduino XIAO board.

I ended up finding [this forum post](https://forum.seeedstudio.com/t/possible-reset-boot-loader-problem/252560) where the OP ended up experiencing what seems similar to the situation I'm currently experiencing here.

However, upon seeing how the recommendation was to purchase and use an external device to flash a functional bootloader into the board, I ended up searching for an alternate method.

As a result, I came across [this medium article](https://naidoff.medium.com/how-to-unbrick-seeduino-xiao-board-without-external-programmer-if-it-was-bricked-while-flashing-fbed494a5034) that provided instructions on how to do that without an external device.

In hindsight, I probably should have run this by you before going any further (especially since my programming knowledge is limited to the basics of C++), but it seems like the bootloader in my device is more functional in that the device isn't stuck/hung up wherever it was before I followed that guide.

Despite all this, there has been no change with HYKU_Configurator.exe's ability to detect the device (including how that same serial exception port error popping up when attempting to flash firmware).

Though now that the bootloader seems like it may actually be in a functional state, there may be a way to flash the firmware or maybe even upload a sketch as mentioned in that medium article.

sssata, 2022-04-02:
Thanks for all the extra work you put in. When you plug in the tablet, does a device called "USB Serial Device" show up in device manager?
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

If so, can you right click on it, open up properties, select the details tab, select "Device instance path" in the dropdown, and get the resulting value listed?

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

In addition, does your computer ever see the tablet as a removable disk drive when you plug it in?

Jaymusta, 2022-04-02:
Ah yes this entire time, it seems that the tablet has consistently shown up as "USB Serial Device (COM3)" in device manager (both before and after flashing the bootloader).

Here is its Device instance path:
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

> USB\VID_2886&PID_002F&MI_00\7&35524896&1&0000

Though after flashing the bootloader, it seems that it also defaults to showing up as "USB Serial Device (COM5)" whenever I have it go into bootloader mode.

So I'm gonna go ahead and include the Device instance path for that as well:
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

> USB\VID_2341&PID_8036&MI_00\9&AA39334&0&0000

sssata, 2022-04-05:
Ok, can you try downloading the .uf2 file from [here](https://github.com/sssata/HYKU_Firmware/releases/tag/v0.5) and drag and drop the file onto the removable disk that appears when you plug the tablet in?

Something like this [tutorial](https://learn.adafruit.com/adafruit-feather-m0-express-designed-for-circuit-python-circuitpython/uf2-bootloader-details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).
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
sssata, 2022-04-09:
1. Yes, the configurator settings are stored on the tablet specifically so you don't have to run some annoying program in the background.

2. The osu map raw input workaround shouldn't have any latency side effects as far as I'm aware.

That being said, thanks so much for all your support on this project, it really helps keep me motivated to work on this. It would be super cool if you do made a video, I'm all for it.

I'd be glad to listen to your feedback here on this git issue.

Jaymusta, 2022-04-11:
- Ayy love to see it.

> That being said, thanks so much for all your support on this project, it really helps keep me motivated to work on this. It would be super cool if you do made a video, I'm all for it.

Man it's crazy how contagious good vibes from things like this can be. This might have just helped me start bringing the momentum back on my end of things.

> I'd be glad to listen to your feedback here on this git issue.

Ah alright, here we go:

### Feedback

- The 3D printed "tablet pen" isn't completely round, which has continued to be a source of frustration while playing osu! so far. The flat side, which I assume is the side that was in contact with the 3D printing surface, often distracts me as I seem to constantly shift my grip around subconsciously. This results in me focusing more on my pen grip more than just playing the game (wrapping grip tape seems to have lessened this a little, though it's definitely still making it harder for any muscle memory to adjust to consistently).
- After my first 2 game sessions with the tablet, I went ahead and applied some tennis grip tape on the lower half of the pen. I ended up having to get some super glue since the tension of wrapping that half of the pen caused it to snap, and [I needed to glue it back together](https://imgur.com/a/SsiUR9R).
- I had no other real issues with the hardware so far, but I did manage to improve how it felt to drag the pen around by creating an incline of sorts with some washers I glued to the rubber feet in the back two corners.
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
I ended up adding 3 washers to each side, adding a total of 3mm of height to the back of the tablet's surface. This made the the tablet match the angle of incline that my old CTH-480 has, and ended up really making a significant improvement in the general feeling of playing osu! with it.

- Finally, other than concerns with having to deal with a device in its developmental stages, one of my friends mentioned how the main thing stopping him from trying the tablet out is that [its max active area's width is considerably smaller than his own tablet area](https://imgur.com/a/aC84bFZ). I believe his current tablet area is still around 120mm in width.

### Suggestions

- I'm not completely familiar with the processes involved with 3D printing objects/parts, but I think altering the process in which the "tablet pen" is printed could help to address the flat edge and durability issues above. There does seem to be another flat surface where the ball joint is screwed in to, so maybe having that surface be in contact with the 3D printing plate could be something to look into. As for the durability, maybe using a more durable type of plastic that doesn't sacrifice too much weight could help if altering the printing patterns doesn't end up helping much with that in mind.
- On the topic of the tablet pen, maybe adding different options for different pen shapes on the product page could be something to add if viable given how its currently 3D printed. Something like having those options be based on the shapes of tablet pens from other known brands: Wacom, Huion, XP-Pen, GAOMON, VEIKK, and maybe even an original pen shape that combines different things from those other brands' pen shapes.
- As for the incline of the tablet's surface, maybe adding the option to choose between rubber pads of different thicknesses to stick onto those back two corners of the device could be something to consider. It's possible that offering differently sized rubber pads would be more viable compared to adding a mechanism similar to what keyboards may have for this purpose.
- And I'm sure the topic/idea of increasing the maximum active area of the tablet has already been introduced by others in the community. So I'm sure you have some kind of solution for that planned out to be addressed eventually (probably once the software side of things are more concrete).

I believe that's pretty much all I have for now, though I'll be sure to add anything else that comes to mind as I keep using the tablet.

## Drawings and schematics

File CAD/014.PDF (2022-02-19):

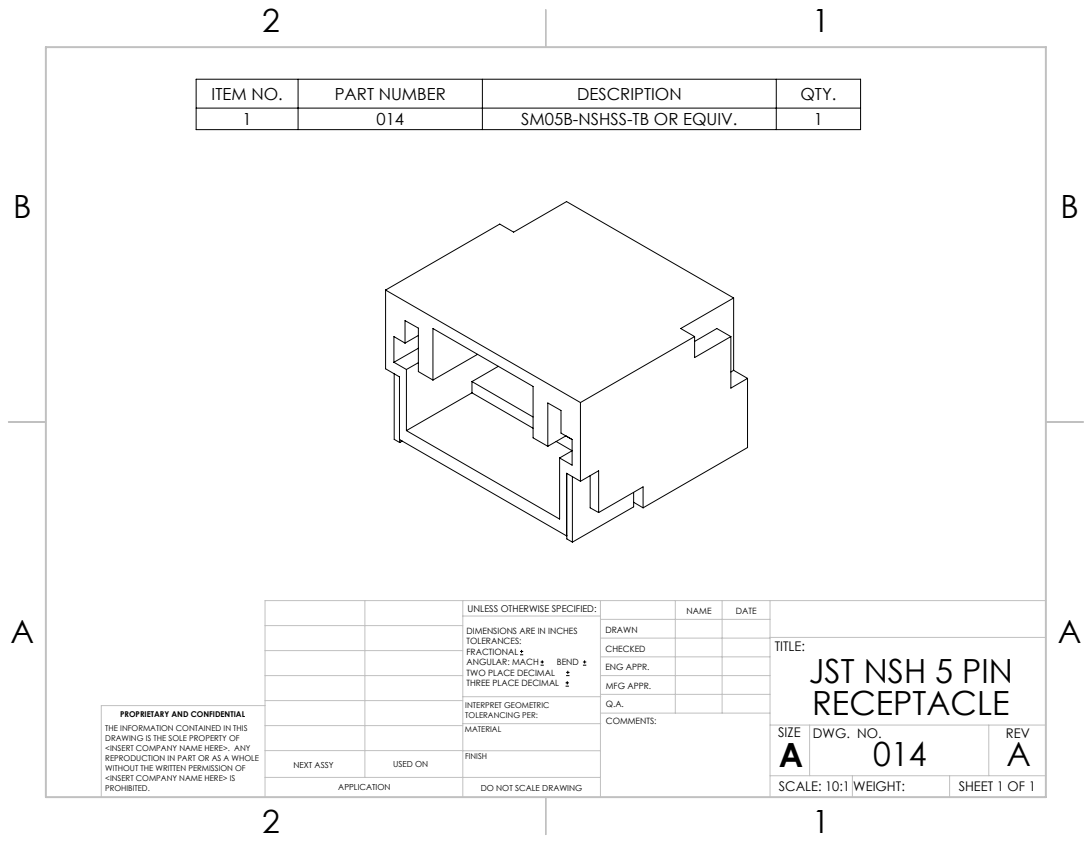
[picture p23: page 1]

ITEM NO. | PART NUMBER | DESCRIPTION | QTY.
1 | 014 | SM05B-NSHSS-TB OR EQUIV. | 1

UNLESS OTHERWISE SPECIFIED: | | NAME | DATE
DIMENSIONS ARE IN INCHES TOLERANCES: FRACTIONAL ANGULAR: MACH BEND TWO PLACE DECIMAL THREE PLACE DECIMAL | DRAWN

CHECKED | | | TITLE: JST NSH 5 PIN RECEPTACLE

ENG APPR.
MFG APPR.

INTERPRET GEOMETRIC TOLERANCING PER: | Q.A.
MATERIAL | | SIZE A | DWG. NO. 014 | REV A

PROPRIETARY AND CONFIDENTIAL
THE INFORMATION CONTAINED IN THIS
DRAWING IS THE SOLE PROPERTY OF
<INSERT COMPANY NAME HERE>. ANY
REPRODUCTION IN PART OR AS A WHOLE
WITHOUT THE WRITTEN PERMISSION OF
<INSERT COMPANY NAME HERE> IS
PROHIBITED.

NEXT ASSY | USED ON | FINISH

APPLICATION | DO NOT SCALE DRAWING | | SCALE: 10:1 WEIGHT: | | SHEET 1 OF 1

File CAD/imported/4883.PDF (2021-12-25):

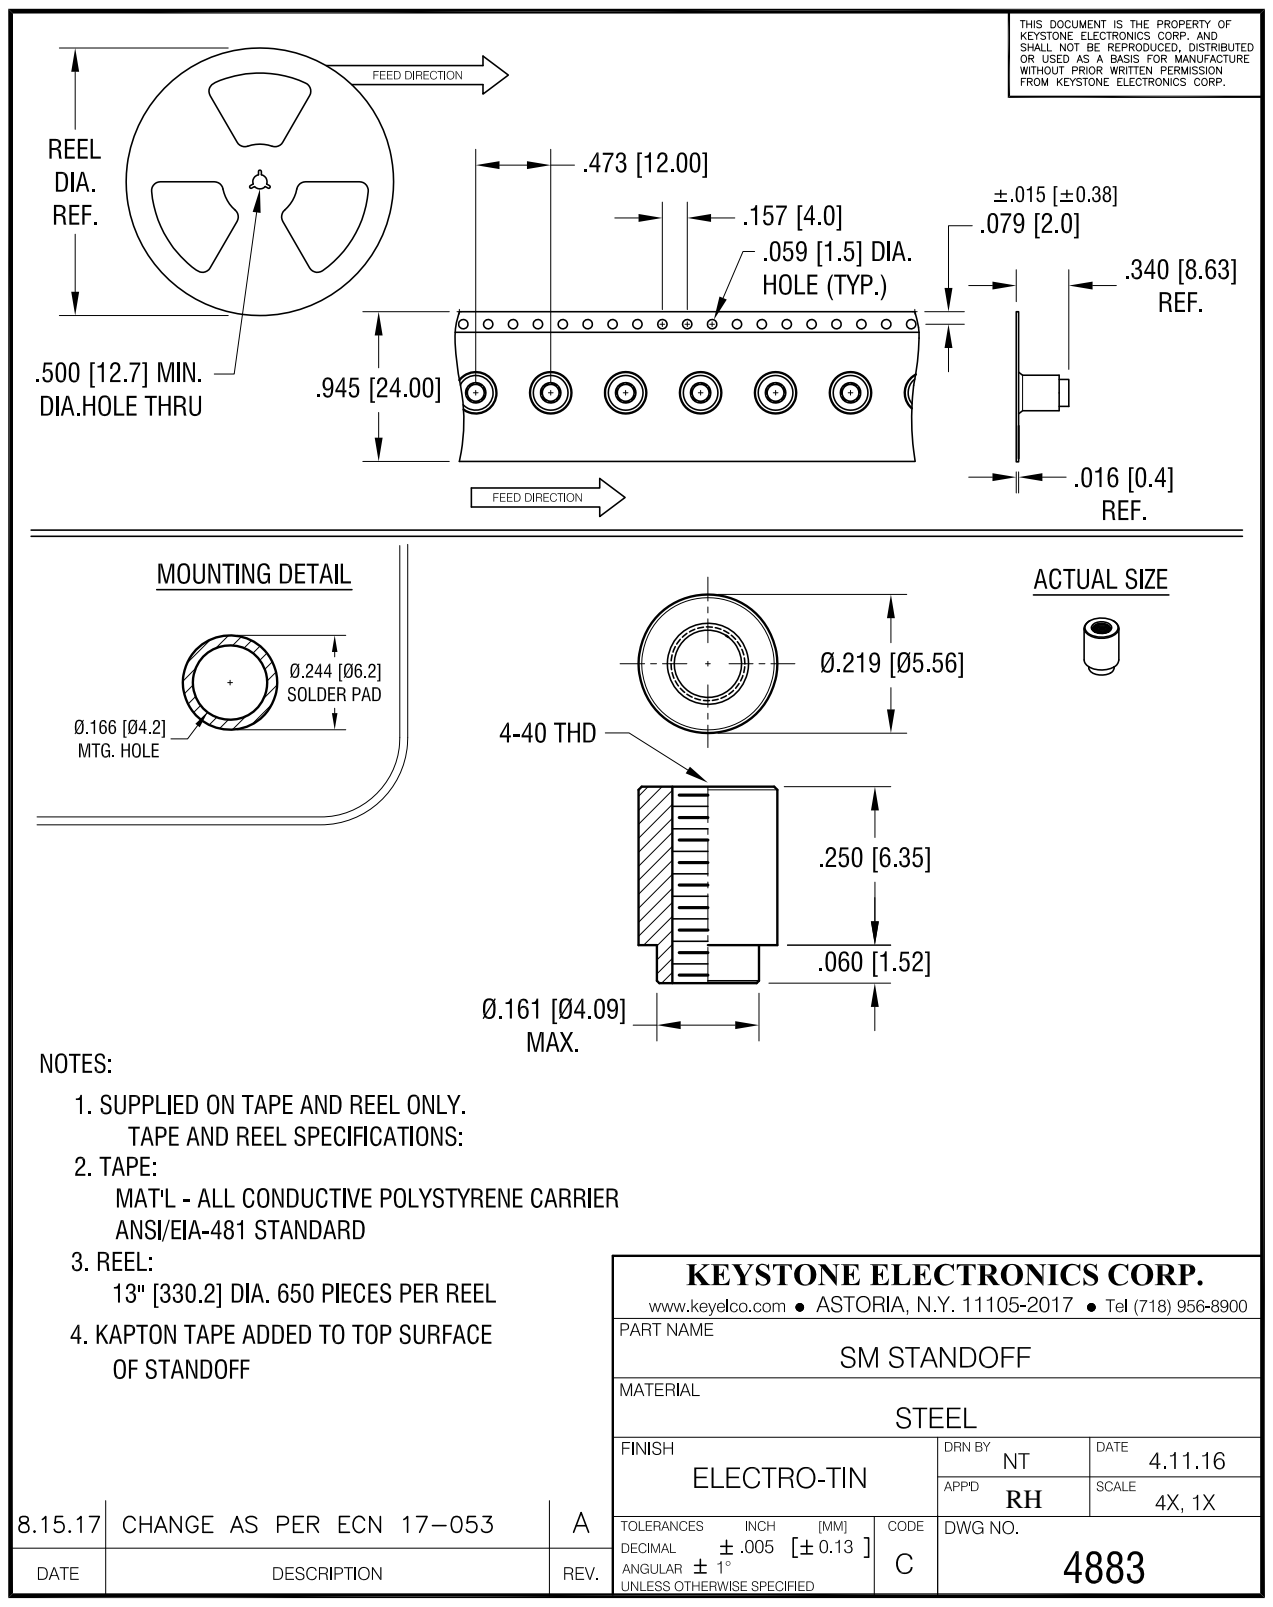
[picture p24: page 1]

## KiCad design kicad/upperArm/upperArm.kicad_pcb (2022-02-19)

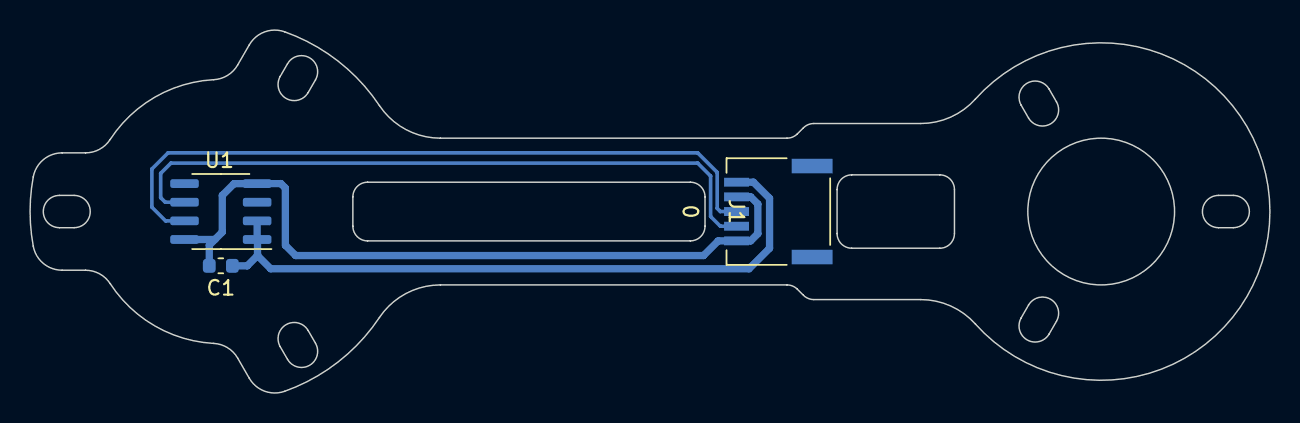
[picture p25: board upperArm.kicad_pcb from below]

Board: 2 copper layers, 84.5 x 24.7 mm, 3 parts (3 on the bottom side), 4 nets.

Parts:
C1: 100nF; C_0603_1608Metric
J1: 0; SM05B-NSHSS-TBLFSN
U1: AS5600; SOIC-8_3.9x4.9mm_P1.27mm

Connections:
+3V3: C1.1, J1.5, U1.1, U1.2
GND: C1.2, J1.1, J1.4, U1.4, U1.8
SCL: J1.3, U1.7
SDA2: J1.2, U1.6

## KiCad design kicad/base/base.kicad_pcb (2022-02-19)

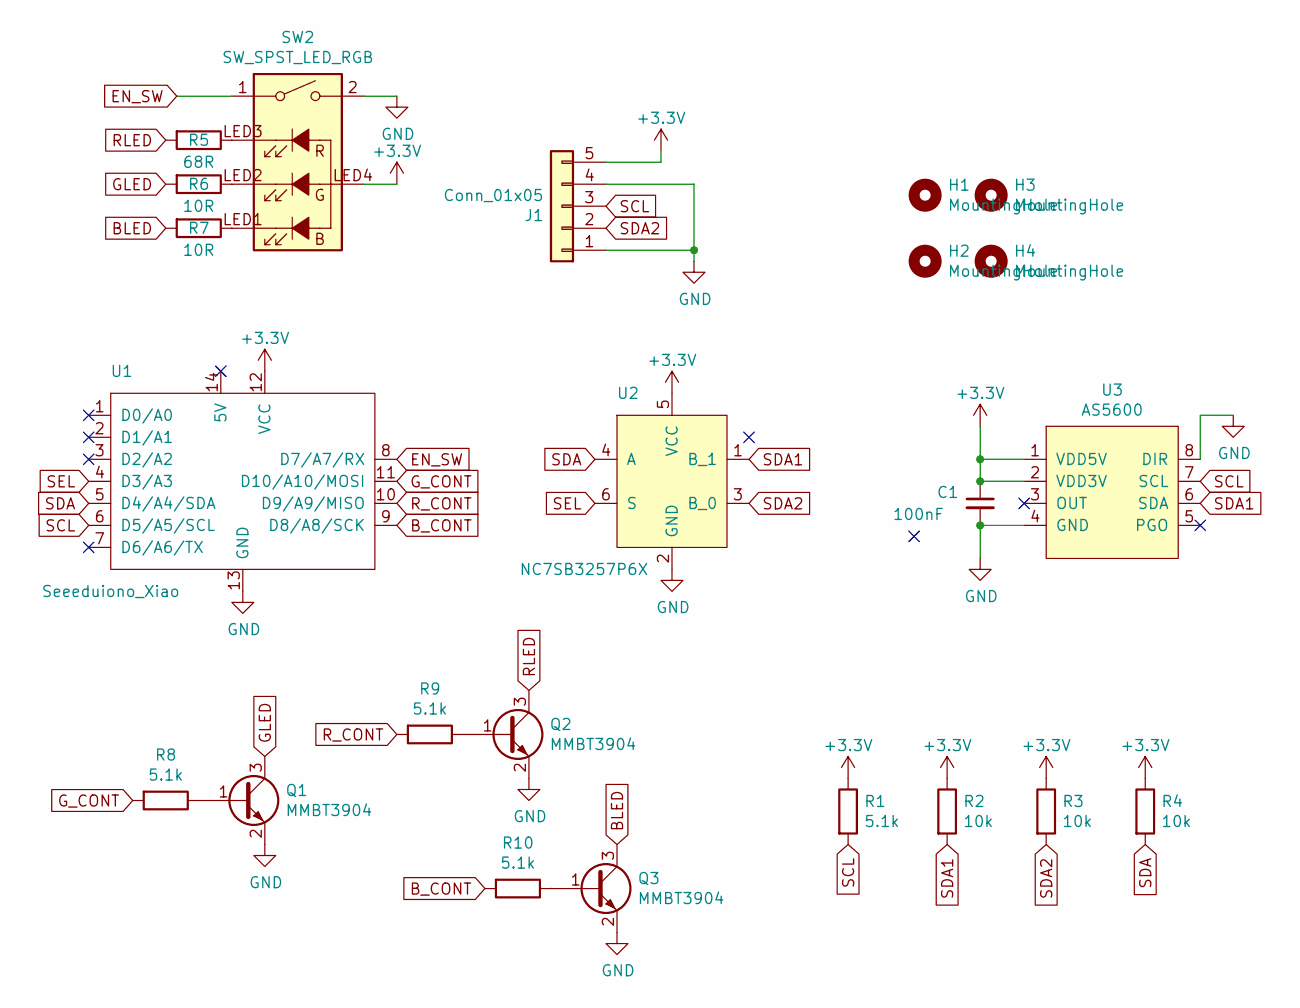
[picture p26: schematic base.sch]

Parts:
C1: 100nF; C_0805_2012Metric; LCSC C49678
H1, H2, H3, H4: MountingHole; MountingHole_3.2mm_M3_Pad_Via
J1: Conn_01x05; SM05B-NSHSS-TBLFSN
Q1, Q2, Q3: MMBT3904; SOT-23; LCSC C20526
R1, R8, R9, R10: 5.1k; R_0805_2012Metric; LCSC C27834
R2, R3, R4: 10k; R_0805_2012Metric; LCSC C17414
R5: 68R; R_0805_2012Metric; LCSC C17802
R6, R7: 10R; R_0805_2012Metric; LCSC C17415
SW2: SW_SPST_LED_RGB; Kailh_socket_MX_SMD_RGB
U1: Seeeduiono_Xiao; Seeeduino_Xiao
U2: NC7SB3257P6X; SOT-363_SC-70-6
U3: AS5600; SOIC-8_3.9x4.9mm_P1.27mm

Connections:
+3V3: C1.1, J1.5, R1.1, R2.1, R3.1, R4.1, SW2.LED4, U1.12 (VCC), U2.5 (VCC), U3.1 (VDD5V), U3.2 (VDD3V)
BLED: Q3.3 (C), R7.2
B_CONT: R10.2, U1.9 (D8/A8/SCK)
EN_SW: SW2.1, U1.8 (D7/A7/RX)
GLED: Q1.3 (C), R6.2
GND: C1.2, J1.1, J1.4, Q1.2 (E), Q2.2 (E), Q3.2 (E), SW2.2, U1.13 (GND), U2.2 (GND), U3.4 (GND), U3.8 (DIR)
G_CONT: R8.2, U1.11 (D10/A10/MOSI)
unnamed: Q1.1 (B), R8.1
unnamed: Q2.1 (B), R9.1
unnamed: Q3.1 (B), R10.1
unnamed: R5.1, SW2.LED3
unnamed: R6.1, SW2.LED2
unnamed: R7.1, SW2.LED1
RLED: Q2.3 (C), R5.2
R_CONT: R9.2, U1.10 (D9/A9/MISO)
SCL: J1.3, R1.2, U1.6 (D5/A5/SCL), U3.7 (SCL)
SDA: R4.2, U1.5 (D4/A4/SDA), U2.4 (A)
SDA1: R2.2, U2.1 (B_1), U3.6 (SDA)
SDA2: J1.2, R3.2, U2.3 (B_0)
SEL: U1.4 (D3/A3), U2.6 (S)

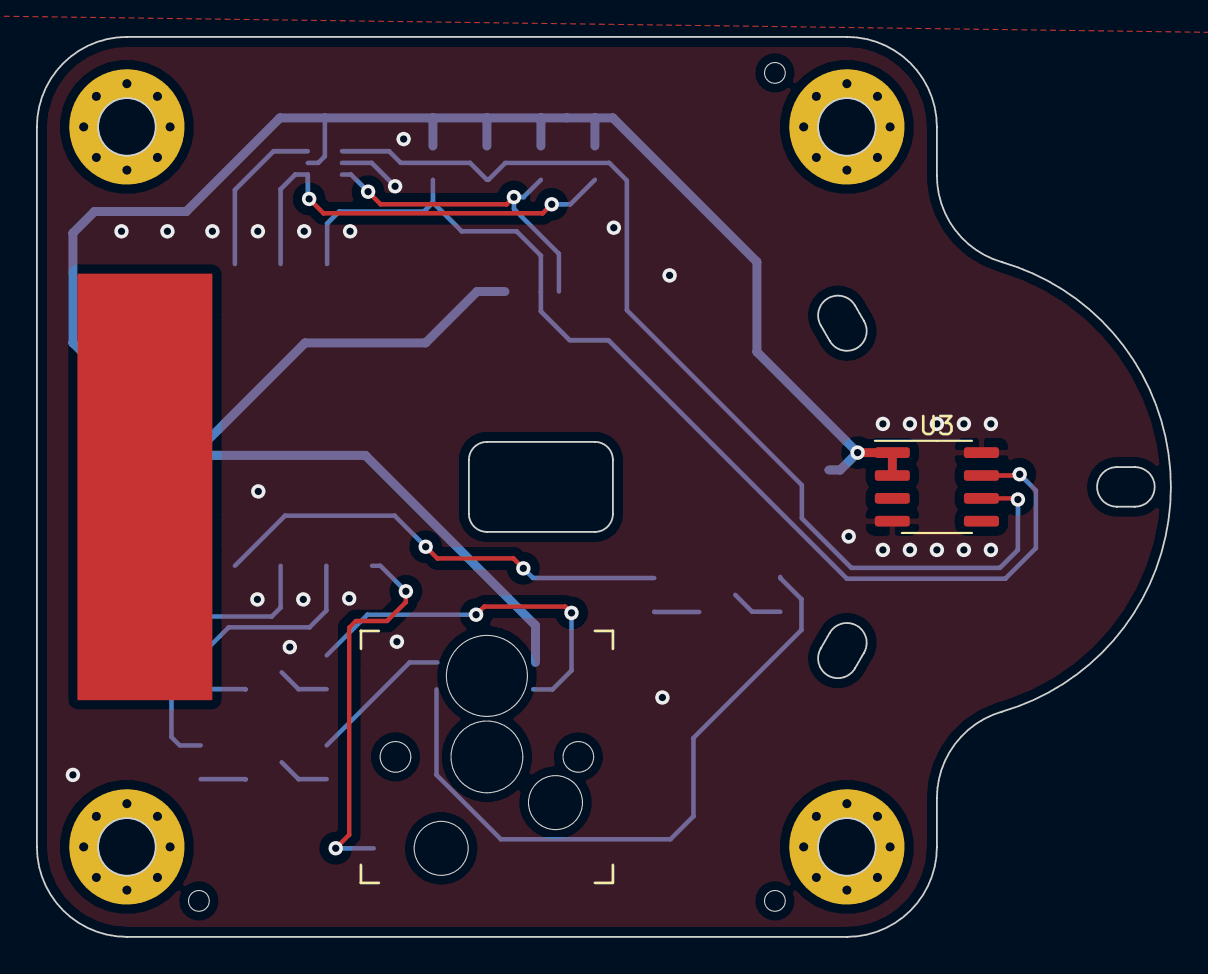
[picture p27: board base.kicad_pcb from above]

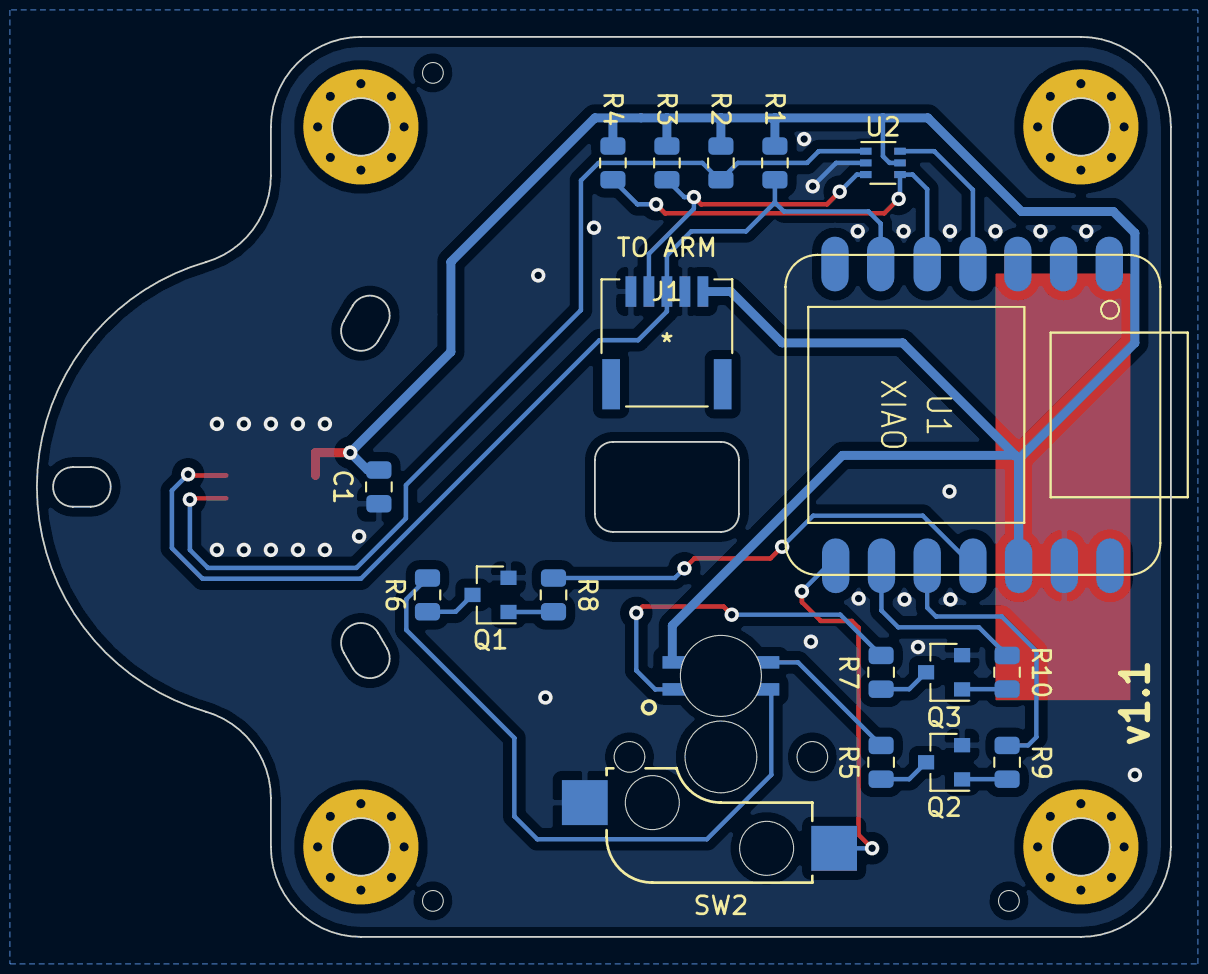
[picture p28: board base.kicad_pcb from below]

Board: 2 copper layers, 63.0 x 50.0 mm, 23 parts (17 on the bottom side), 20 nets.

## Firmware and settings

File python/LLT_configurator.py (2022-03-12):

import os
import pathlib
import subprocess
import sys
import threading
import time
import tkinter as tk
import tkinter.tix
from ast import Call, Str
from pprint import pformat, pprint
from tkinter import messagebox, ttk
import requests
from typing import List, Callable, Union
import json
import logging

import serial
import serial.tools.list_ports
import tktooltip
from github import Github
import screeninfo

PID = 0x802F
VID = 0x2886


import ctypes

BG_COLOR = "#b3b3b3"
AREA_COLOR = "#a3ebff"
AREA_BORDER_COLOR = "#0083c9"

FRAME_BG_COLOR = "SystemButtonFace"
FRAME_BG_COLOR = "#EBEBF0"


user = ctypes.windll.user32


class FirmwareRelease:
    def __init__(self, release_name: str, release_download_url: str) -> None:
        self.release_name = release_name
        self.release_download_url = release_download_url


def resolve_resource_path(relative_path: str):
    """Get absolute path to resource, works for dev and for PyInstaller"""
    try:
        # PyInstaller creates a temp folder and stores path in _MEIPASS
        base_path = sys._MEIPASS
    except Exception:
        base_path = os.path.abspath(".")
        base_path = pathlib.Path(".").resolve()

    return pathlib.Path(base_path) / relative_path
    # return os.path.join(base_path, relative_path)


def get_serial_port_with_pid_vid(pid, vid):
    """Return the port name of the correct PID, VID"""
    port_list = serial.tools.list_ports.comports()
    for port in port_list:
        if port.pid == pid and port.vid == vid:
            return port.name

    return None


class RECT(ctypes.Structure):
    _fields_ = [
        ("left", ctypes.c_ulong),
        ("top", ctypes.c_ulong),
        ("right", ctypes.c_ulong),
        ("bottom", ctypes.c_ulong),
    ]

    def dump(self):
        return self


class MONITORINFO(ctypes.Structure):
    _fields_ = [
        ("cbSize", ctypes.c_ulong),
        ("rcMonitor", RECT),
        ("rcWork", RECT),
        ("dwFlags", ctypes.c_ulong),
    ]


monitor_list = screeninfo.get_monitors()
monitor_primary = [x.name for x in monitor_list if x.is_primary][0]
monitor_object_primary = [x for x in monitor_list if x.is_primary][0]
monitor_list_names = [x.name for x in monitor_list]

is_calibration_canceled = None

for monitor in monitor_list:
    print(str(monitor))


class MonitorTabletRectangle:
    """Holds info on monitor or tablet coords"""

    def __init__(self, x0, y0, x1, y1) -> None:
        self.x0 = x0
        self.y0 = y0
        self.x1 = x1
        self.y1 = y1

    def __eq__(self, other):
        if not isinstance(other, MonitorTabletRectangle):
            # don't attempt to compare against unrelated types
            return NotImplemented

        return (
            self.x0 == other.x0
            and self.y0 == other.y0
            and self.x1 == other.x1
            and self.y1 == other.y1
        )

    def __str__(self):
        return pformat(self.__dict__)


class MonitorBoundingBox:
    def __init__(self, min_x, min_y, max_x, max_y) -> None:
        self.min_x = min_x
        self.min_y = min_y
        self.max_x = max_x
        self.max_y = max_y


def get_scaling_factor(canvas_width, canvas_height, bounding_box: MonitorBoundingBox):
    """Returns the scaling factor to draw a rectangle on a canvas
    given the canvas dimensions and bounding box"""

    scale_factor_x = (canvas_width * 1.0) / (bounding_box.max_x - bounding_box.min_x)
    scale_factor_y = (canvas_height * 1.0) / (bounding_box.max_y - bounding_box.min_y)
    return min(scale_factor_x, scale_factor_y)


def shift_origin(
    monitor_rect: MonitorTabletRectangle, bounding_box: MonitorBoundingBox
):
    """Shift origin of the given screen areas"""
    monitor_rect.x0 -= bounding_box.min_x
    monitor_rect.y0 -= bounding_box.min_y
    monitor_rect.x1 -= bounding_box.min_x
    monitor_rect.y1 -= bounding_box.min_y


def center_in_canvas_x_gap(
    canvas_width,
    canvas_height,
    scaling_factor,
    bounding_box: MonitorBoundingBox,
):
    """Returns the x dimension gap required to center a rectangle a canvas given args.
    Minimum of 0.
    Args:   canvas_with
            canvas_height
            scaling_factor
            bounding_box"""
    gap_x = (bounding_box.max_x - bounding_box.min_x) * scaling_factor - canvas_width
    return max(0, gap_x)


def center_in_canvas_y_gap(
    self,
    canvas_width,
    canvas_height,
    scaling_factor,
    bounding_box: MonitorBoundingBox,
):
    """Returns the x dimension gap required to center a rectangle a canvas given args.
    Minimum of 0.
    Args:   canvas_with
            canvas_height
            scaling_factor
            bounding_box"""
    gap_y = (bounding_box.max_y - bounding_box.min_y) * scaling_factor - canvas_height
    return max(0, gap_y)
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

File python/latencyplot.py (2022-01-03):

import matplotlib.pyplot as plt
import matplotlib
import numpy as np
from curlyBrace import curlyBrace

t = np.linspace(0,30,1000)

pos_real = 3 * t

slow_cost = 15
pos_slow = np.floor(pos_real/slow_cost)*slow_cost

fast_const = 6
pos_fast = np.floor(pos_real/fast_const)*fast_const

fig, ax = plt.subplots()

print(t)
print(pos_real)


ax.plot(t, pos_real, '--')
ax.plot(t, pos_slow)
ax.plot(t, pos_fast)
curlyBrace(fig, ax, [10.4,30], [10.4,24], 0.26, bool_auto=True, str_text="", color='black', lw=2, int_line_num=1)
ax.annotate("up to 6 px of position error at 500 Hz", (11.6,27), va="center")
curlyBrace(fig, ax, [15.4,45], [15.4,30], 0.1, bool_auto=True, str_text="", color='black', lw=2, int_line_num=1)
ax.annotate("up to 15 px of position error\nat 200 Hz", (16.8,37.5), va="center")
ax.set_ylabel("Position (px)")
ax.set_xlabel("Time (ms)")
ax.set_title("Effect of Polling Rate at 3000 px/second movement")
ax.legend(("Actual", "Sensed (200 Hz)", "Sensed (500 Hz)"))

plt.show()

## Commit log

2021-12-25 removed temp files
    [017 AREA PCB.SLDPRT, 902 FINAL ASSY.SLDASM]
2022-01-03 updated stuff
    [016 LOWER ARM PCB.SLDPRT, 016 LOWER ARM PCB.STL, 021 PEN.STL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]
2022-01-14 changed pen shape
    [016 LOWER ARM PCB.SLDPRT, 016 LOWER ARM PCB.STL, 016 LOWER ARM TEST1.STL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]
2022-02-01 added exp filter config
2022-02-19 added left hand support, updated pcb with logo, updated pen geometry
    [014.SLDDRW, 018 UPPER WIRE.SLDPRT, 021 PEN.SLDPRT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]

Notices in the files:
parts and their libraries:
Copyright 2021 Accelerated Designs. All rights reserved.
